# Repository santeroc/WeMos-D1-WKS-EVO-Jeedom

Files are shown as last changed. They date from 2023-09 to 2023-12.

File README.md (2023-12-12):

# WeMos-D1-WKS-EVO-Jeedom
Module permettant de collecter les informations d'un onduleur WKS-EVO pour les récupérer dans une plateforme domotique Jeedom.

## Description détaillée

Ce projet a pour objectif de mettre en œuvre un module permettant de collecter les informations en provenance d’un onduleur solaire hybride WKS, de contrôler à l’aide de deux sondes thermiques la température haute (côté onduleur), la température basse (côté batteries) et de démarrer un système de ventilation si nécessaire. Ce module maintient également la date et l’heure à jour en face du changement d'heure d'été et d'hiver dans l'onduleur (qui n'est pas connecté au réseau informatique). La carte ARCELI WeMos D1 R2, à la base de ce module, embarque une architecture ESP8266 et une carte WIFI intégrée.

## Recommandation
Il est vivement recommandé d'avoir de bonnes connaissances en électricité générale avant de réaliser ou de manipuler tout câblage électrique.
Ceci afin d'appréhender au minimum les risques d'électrocution.

## Structure du projet
- **Documentation\\** : Documentation du projet à lire avant de commencer
	- ``WeMos-D1-WKS-EVO-Jeedom.pdf`` : Document de base nécessaire pour fabriquer le projet et utiliser le code source ci-dessous.
	- ``Plan_De_Cablage_Electrique.pdf`` : Plan de câblage électrique de la solution.
	- ``Plan_De_Cablage_Electrique_Element_Positon_Plan.pdf`` / ``Plan_De_Cablage_Electrique_Element_Positon_Plan.html`` : Composants du plan de câblage avec position sur plan.
	- ``Manuel-WKS-EVO-FR-2021-2-2 - Avec Mes Paramétres.pdf`` : Manuel du WKS-EVO avec mes paramètres et mes commentaires en couleurs.
- **Facade-3D\\**     : Façade imprimable en 3D réalisée avec FreeCAD 0.20
	- ``Facade-v3.FCStd`` : Projet de façade réalisé avec FreeCAD.
	-  ``Facade-v3-Body (Meshed).stl`` : Fichier Mesh de la façade 3D à transmettre pour l'impression 3D.
- **Source\\**        : Code source du projet 
	-  ``WKS_ip_Claude_LCD2004_Et_Temp_H_B_R_T_Reboot_STOndul.ino`` : Code source Arduino à adapter selon la documentaiton ci-dessus.
	
## Version
**Dernière version stable :** 7.8

## Auteur
* **Claude Santero** _alias_ [@santeroc](https://github.com/santeroc)

## Licence

Ce projet est sous licence ``GPLv3`` - voir le fichier [LICENSE.md](LICENSE.md) pour plus d'informations.

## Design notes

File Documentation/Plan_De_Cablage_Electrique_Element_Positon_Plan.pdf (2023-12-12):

KIT SOLAIRE‐DISCOUNT
Arcle | Site | Quanté | Posion / Plan | URL
Seconneur Baerie Unipolaire | Kit Solaire Discount | 1 | B | hps://kitsolaire‐discount.com/fr/coffrets‐de‐protecon/959‐seconneur‐mono‐baerie‐8425511453855.html
PORTE‐FUSIBLE MEGA‐FUSE ‐ VICTRON ENERGY | Kit Solaire Discount | 1 | A | hps://kitsolaire‐discount.com/fr/protecons‐baerie/590‐porte‐fusible‐mega‐fuse‐victron‐energy‐8414824007282.html
FUSIBLE MEGA‐FUSE 200A/32V POUR SYSTEME 12V / 24V | Kit Solaire Discount | 1 | A | hps://kitsolaire‐discount.com/fr/protecons‐baerie/983‐fusible‐mega‐fuse‐200a32v‐pour‐systeme‐12v‐24v‐8414824007282.html
Baerie 100ah 12v Gel décharge Ulmatron | Kit Solaire Discount | 2 | H | hps://kitsolaire‐discount.com/fr/baeries‐solaires‐12v/498‐baerie‐100ah‐12v‐gel‐decharge‐lente‐ulmatron‐8425511454166.html
Cable de Connexion Inter‐baeries 20cm‐25mm² | Kit Solaire Discount | 1 | G | hps://kitsolaire‐discount.com/fr/cable‐connecques‐ouls/88‐cable‐de‐connexon‐inter‐baeries‐20cm‐25mm2‐8414824002911.html
Coffret DC 3kW 25A ‐ 600V ‐ 2 string ‐ 1 MPPT ‐ GENERAL ELECTRIC | Kit Solaire Discount | 1 | J | hps://kitsolaire‐discount.com/fr/coffrets‐de‐protecon/1618‐coffret‐de‐protecon‐dc‐2‐mppt‐2‐parafoudre‐8414824003123.html
PANNEAU SOLAIRE 400W ‐ SHINGLED ‐ CADRE NOIR ‐ ECODELTA | Kit Solaire Discount | 2 | K | hps://kitsolaire‐discount.com/fr/panneaux‐solaires‐rigides/24‐panneau‐solaire‐400w‐shingled‐cadre‐noir‐ecodelta‐8424511843147.html

AMAZON
Arcle | Site | Quanté | Posion / Plan | URL
enjoysolar 15m Câble de raccordement professionnel 4mm² pour panneau solaire avec câble solaire MC‐4 | AMAZON | 1 | N + O | hps://www.amazon.fr/gp/product/B07TLWT9B7/ref=ppx_yo_dt_b_asin_tle_o00_s00?ie=UTF8&th=1
eXODA Câble de Baerie 50cm câble d'alimentaon en cuivre 25 mm² avec cosses à œillets M8 12V câble de Voiture | AMAZON | 1 | C | hps://www.amazon.fr/eXODA‐Baerie‐Dalimentaon‐%C5%93illets‐Voiture/dp/B01C62XC5Y/ref=sr_1_20?keywords=cable+25mm2+m8&qid=1647788559&refinements=p_76%3A437878031&rnid=437877031&rps=1&sprefix=cable+25mm2+M8%2Caps%2C61&sr=8‐20
eXODA Câble de Baerie 150cm câble d'alimentaon en cuivre 25 mm² avec cosses à œillets M8 12V câble de Voiture | AMAZON | 1 | E | hps://www.amazon.fr/eXODA‐Baerie‐Dalimentaon‐%C5%93illets‐Voiture/dp/B01JH1D162/ref=sr_1_2?__mk_fr_FR=%C3%85M%C3%85%C5%BD%C3%95%C3%91&crid=1D0QEDQ3W1SMA&keywords=C%C3%A2ble+de+Baerie+150cm+c%C3%A2ble+d%27alimentaon+en+cuivre+25+mm%C2%B2+avec+cosses+%C3%A0+%C5%93illets+M8&qid=1647789099&sprefix=c%C3%A2ble+de+baerie+150cm+c%C3%A2ble+d%27alimentaon+en+cuivre+25+mm+avec+cosses+%C3%A0+%C5%93illets+m8%2Caps%2C50&sr=8‐2
Clef Triange Pour Ouvrir L'Armoire 32U d'occasion | AMAZON | 1 | | hps://www.amazon.fr/gp/product/B08L3DDSLL/ref=ppx_yo_dt_b_asin_tle_o00_s00?ie=UTF8&psc=1

MYSHOP SOLAIRE
Arcle | Site | Quanté | Posion / Plan | URL
Câble électrique souple de 1.5m en 25mm² ‐ cosse M8 ‐ M10 | MyShop Solaire | 1 | F | hps://www.myshop‐solaire.com/cable‐electrique‐souple‐de‐1‐5m‐ser‐de‐cosse‐m8‐m10‐en‐25mm2‐_r_709_tpid_20_i_3028.html
Câble électrique souple de 0,4m en 25mm² ‐ cosse M8 ‐ M10 | MyShop Solaire | 1 | D | hps://www.myshop‐solaire.com/cable‐bmv‐0‐4m‐ser‐de‐cosse‐m8‐m10‐en‐25mm2‐_r_709_tpid_20_i_946.html
Unifix 800 EGF support de fixaon au sol à viser ou lester | MyShop Solaire | 1 | R | hps://www.myshop‐solaire.com/unifix‐800‐egf‐support‐de‐fixaon‐au‐sol‐a‐viser‐ou‐lester‐_r_1055_i_3002.html
Support dalle béton pour Unifix 800 EGF support de fixaon au sol | MyShop Solaire | 1 | R | hps://www.myshop‐solaire.com/support‐dalle‐beton‐pour‐unifix‐800‐egf‐support‐de‐fixaon‐au‐sol‐_r_1055_i_3003.html#caracterisque

WATTUNEED
Arcle | Site | Quanté | Posion / Plan | URL
Onduleur hybride WKS Evo 3kVA 24V ‐ Code Promo "inthekitchen" | Wa U Need | 1 | I | hps://www.wauneed.com/fr/conversseurs‐230v/12232‐onduleur‐hybride‐wks‐evo‐3kva‐24v‐0712971139954.html
Câble solaire 2X4mm² avec type MC4 (vendu au mètre) / 3m | Wa U Need | 1 | L + M | hps://www.wauneed.com/fr/cables‐et‐connecques/2317‐cable‐solaire‐2x4mm‐avec‐type‐mc4‐0712971133280.html#/longueur_du_c%C3%A2ble‐3m

MAGASINS DIVERS
Arcle | Site | Quanté | Posion / Plan | URL
Castorama (Gouloe, Gaine ICTA,…) | Castorama | 1
Dalle grenaillée Lagos ton pierre 40 x 40 cm, ép.4 cm (Pete Terrasse + Leste) | Castorama | 21 | R | hps://www.castorama.fr/dalle‐grenaillee‐lagos‐ton‐pierre‐40‐x‐40‐cm‐ep‐4‐cm/3454976249258_CAFR.prd
Cables & Vis | Castorama | 1
Plaque de plâtre feu Planodis 250 x 120 cm, ép.12,5 mm | Castorama | 1 | | hps://www.castorama.fr/plaque‐de‐platre‐feu‐planodis‐250‐x‐120‐cm‐ep‐12‐5‐mm‐vendue‐a‐la‐plaque‐zone‐nord/3334160434762_CAFR.prd
Coffret Electrique | Castorama | 1
Armoire Réseau 32U d'occasion | Le Bon Coin | 1

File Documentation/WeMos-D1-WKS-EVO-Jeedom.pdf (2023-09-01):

Dernière Révision : 24/08/2023 - | Réalisation : Claude Santero.

Présentation Du Projet WeMos UI (UPS Interface) :

Le projet WeMos UI a pour objectif de mettre en œuvre une interface permettant de collecter les informations en provenance d’un onduleur solaire hybride WKS, de contrôler à l’aide de deux sondes thermiques la température haute (côté onduleur), la température basse (côté batteries) et de démarrer un système de ventilation si nécessaire. Il maintient également la date et l’heure à jour. La carte ARCELI WeMos D1 R2 embarque une architecture ESP8266 et une carte WIFI intégrée.

Le logiciel embarqué se connecte comme un client au réseau WIFI dont le SSID et le mot de passe sont codés en dur à la compilation. Le système met automatiquement à jour son horloge interne à l’aide d’un client NTP, en prenant en charge l’heure local et les changements d’heure. La date et l’heure sont transmises à l’onduleur au démarrage du module puis tous les jours à 6H du matin via son port série. Un affichage LCD indique la date et l’heure ainsi que la température et le taux d’humidité en partie haute (côté onduleur) et en partie basse (côté batteries). Le logiciel déclenche un relais en fonction de ces températures et / ou en fonction de l’heure pour refroidir l’ensemble. En cas d’anomalie des sondes thermiques ou si la carte venait à être physiquement éteinte, la ventilation se déclenche immédiatement. Le fonctionnement du relais et de la ventilation a été réalisé de tel sorte que ce soit le logiciel qui coupe le relais et donc la ventilation. En l’absence d’un ordre explicit du logiciel sur la carte pour couper le relais, la ventilation est donc toujours en service. Enfin, le logiciel embarque un serveur web permettant présenter les informations collectées sur le port série de l’onduleur, la température et l’humidité au niveau des sondes de température haute et basse et l’état du relais pour la ventilation. Ces informations sont ensuite collectées sur une plateforme Jeedom à l’aide du plugin « Script » toutes les minutes.

Ce document et ce projet sont libres de droit sous licence GPLv3. Merci simplement de respecter son auteur.

### Vous pouvez retrouver l’ensemble de ce projet sur GitHub à l’adresse : https://github.com/santeroc/WeMos-D1-WKS-EVO-Jeedom.git ainsi que toutes mes documentations et tous mes projets sur mon référentiel

GitHub à l’adresse : https://santeroc.github.io.

Liste des articles utilisés dans cette documentation :

- La carte ARCELI :
ARCELI Programme Arduino UNO Compatible avec la Carte de développement WeMos D1 R2 WiFi ESP8266 de Arduino IDE https://www.amazon.fr/gp/product/B07J2QKNHB/ref=ppx_yo_dt_b_asin_title_o02_s00?ie=UTF8&psc=1 (https://www.amazon.fr/gp/product/B07J2QKNHB/ref=ppx_yo_dt_b_asin_title_o02_s00?ie=UTF8&psc=1)
- Câbles de liaisons entre les différents modules :
WheateFull 120 pièces Multicolore Dupont Wire 40pin mâle à femelle + 40pin mâle à mâle + 40pin femelle à femelle Panneau de câbles de cavalier Kit de câbles de ruban pour Arduino https://www.amazon.fr/gp/product/B06XD8NBTZ/ref=ppx_yo_dt_b_asin_title_o06_s00?ie=UTF8&psc=1 (https://www.amazon.fr/gp/product/B06XD8NBTZ/ref=ppx_yo_dt_b_asin_title_o06_s00?ie=UTF8&psc=1)
- Le LCD (étape 1) :
SunFounder IIC I2C TWI Serial 2004 20x4 LCD Module Shield Compatible with Arduino R3 MEGA 2560
https://www.amazon.fr/gp/product/B01GPUMP9C/ref=ppx_yo_dt_b_asin_title_o03_s00?ie=UTF8&psc=1 (https://www.amazon.fr/gp/product/B01GPUMP9C/ref=ppx_yo_dt_b_asin_title_o03_s00?ie=UTF8&psc=1)
- Les sondes thermiques DHT22 AM2302 (étape 2) :
AZDelivery DHT22 AM2302 Capteur de Température et d’Humidité avec Câble Compatible avec Arduino et Raspberry Pi incluant Un E-Book! https://www.amazon.fr/dp/B078SVZB1X/?coliid=I3SM4RYJJS3798&colid=3CZB4MB46B54F&psc=1&ref_=lv_ov_lig_dp_it (https://www.amazon.fr/dp/B078SVZB1X/?coliid=I3SM4RYJJS3798&colid=3CZB4MB46B54F)
- Le convertisseur RS232 (étape 3) :
DollaTek MAX3232 RS232 Serial Port vers TTL Convertisseur Module DB9 Connecteur W / 4 Jump Cables https://www.amazon.fr/gp/product/B07DK3874B/ref=ppx_yo_dt_b_asin_title_o07_s02?ie=UTF8&psc=1 (https://www.amazon.fr/gp/product/B07DK3874B/ref=ppx_yo_dt_b_asin_title_o07_s02?ie=UTF8&psc=1)
- Connecteur de raccordement (étape 4) :
YIOVVOM Connecteur de dérivation DB9 vers borne de câblage RS232 D-SUB adaptateurs série mâles Carte de dérivation de Port Module sans Soudure avec boîtier (Adaptateur série mâle + écrou) https://www.amazon.fr/gp/product/B071DS5GTW/ref=ppx_yo_dt_b_asin_title_o07_s01?ie=UTF8&th=1 (https://www.amazon.fr/gp/product/B071DS5GTW/ref=ppx_yo_dt_b_asin_title_o07_s01?ie=UTF8&th=1)
- Le relais (étape 5) :
ARCELI 5pcs 5V Un Blindage de Carte de Module de Relais à 1 Canal pour Arduino (déclencheur de Bas Niveau) https://www.amazon.fr/gp/product/B07RJFJJZM/ref=ppx_yo_dt_b_asin_title_o00_s00?ie=UTF8&psc=1 (https://www.amazon.fr/gp/product/B07RJFJJZM/ref=ppx_yo_dt_b_asin_title_o00_s00?ie=UTF8&psc=1)
- Le convertisseur 220v – 12v DC (étape 5) :
HuaTec Eaglerise Transformateur LED 12V 15W Tension Constant Ultra Fin pour bande de LED Bloc d'Alimentation Driver LED https://www.amazon.fr/dp/B082VD3QM7/?coliid=I1AE1KZV4JGJ14&colid=TFC9A61478GS&psc=1&ref_=lv_ov_lig_dp_it (https://www.amazon.fr/dp/B082VD3QM7/?coliid=I1AE1KZV4JGJ14&colid=TFC9A61478GS)
- Ventilateur (étape 5) :
Noctua NF-F12 iPPC-2000, Ventilateur Haut Rendement, 3 Broches, 2000 tr./min (120 mm, Noir)
https://www.amazon.fr/dp/B00KEST8PQ/?coliid=I2B3BR5PYC3TEZ&colid=TFC9A61478GS&psc=1&ref_=lv_ov_lig_dp_it (https://www.amazon.fr/dp/B00KEST8PQ/?coliid=I2B3BR5PYC3TEZ&colid=TFC9A61478GS)
- Boite et sa façade (étape 9) :
JOYKK Boîte de Projet pour boîtier électronique en Plastique étanche https://www.amazon.fr/gp/product/B07PK4BPM4/ref=ppx_yo_dt_b_asin_title_o03_s00?ie=UTF8&psc=1 (https://www.amazon.fr/gp/product/B07PK4BPM4/ref=ppx_yo_dt_b_asin_title_o03_s00?ie=UTF8&psc=1)

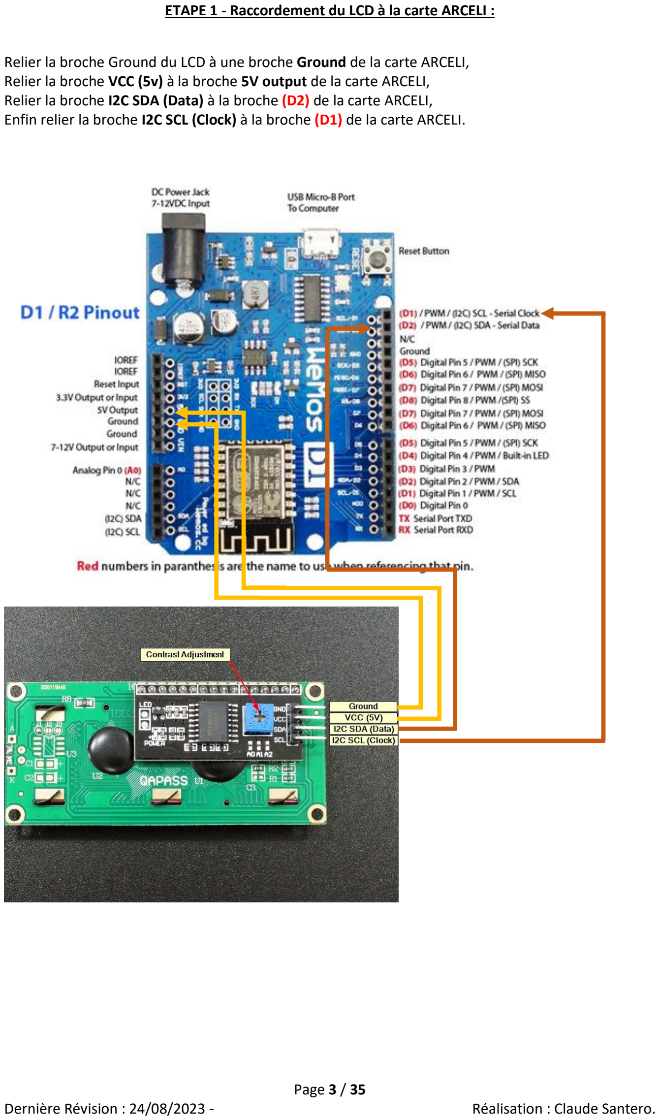
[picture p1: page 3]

ETAPE 1 - Raccordement du LCD à la carte ARCELI :

Relier la broche Ground du LCD à une broche Ground de la carte ARCELI, Relier la broche VCC (5v) à la broche 5V output de la carte ARCELI, Relier la broche I2C SDA (Data) à la broche (D2) de la carte ARCELI, Enfin relier la broche I2C SCL (Clock) à la broche (D1) de la carte ARCELI.

ETAPE 2 - Raccordement des sondes DHT22 AM2302 à la carte ARCELI :

Relier les broches « - » des DHT22 à une broche Ground de la carte ARCELI, Relier les broches « + » des DHT22 à la broche 5V output de la carte ARCELI, Relier la broche OUT du DHT Bas (B) à la broche (D3) de la carte ARCELI, Enfin relier la broche OUT du DHT Haut (H) à la broche (D4) de la carte ARCELI.

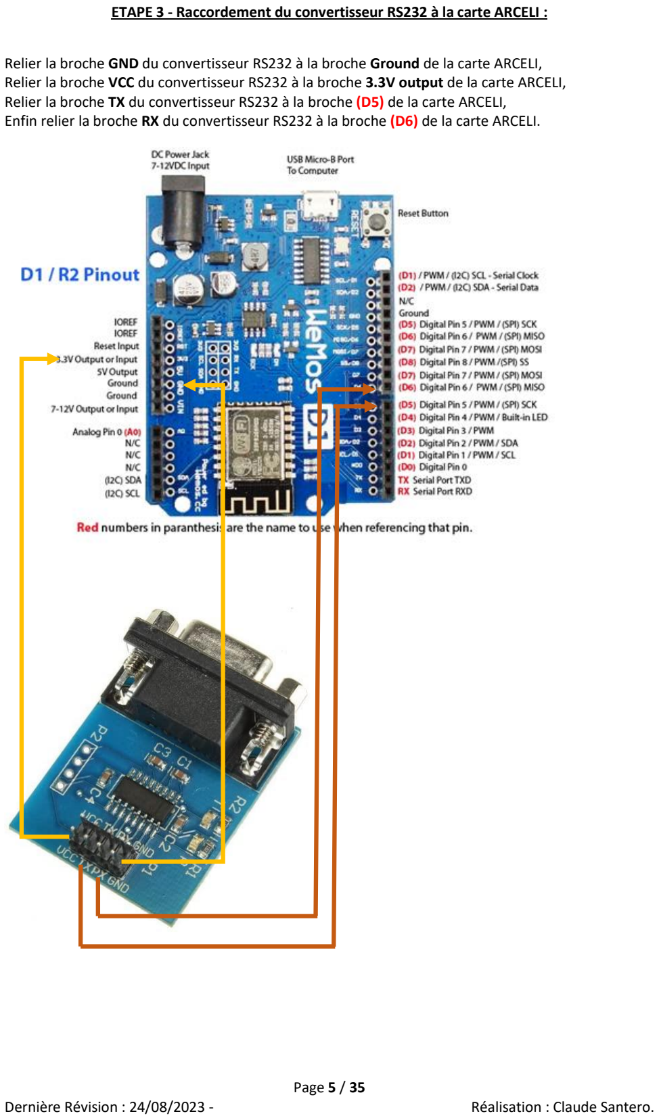
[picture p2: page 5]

ETAPE 3 - Raccordement du convertisseur RS232 à la carte ARCELI :

Relier la broche GND du convertisseur RS232 à la broche Ground de la carte ARCELI, Relier la broche VCC du convertisseur RS232 à la broche 3.3V output de la carte ARCELI, Relier la broche TX du convertisseur RS232 à la broche (D5) de la carte ARCELI,
Enfin relier la broche RX du convertisseur RS232 à la broche (D6) de la carte ARCELI.

ETAPE 4 - Raccordement du convertisseur RS232 à l’onduleur :

Le connecteur RJ45 se connecte au port COM (série ou RS232) de l’onduleur. Le connecteur RS232 (DB9) vient se connecter sur le convertisseur RS232 préparé en étape 3.

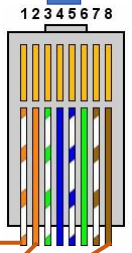
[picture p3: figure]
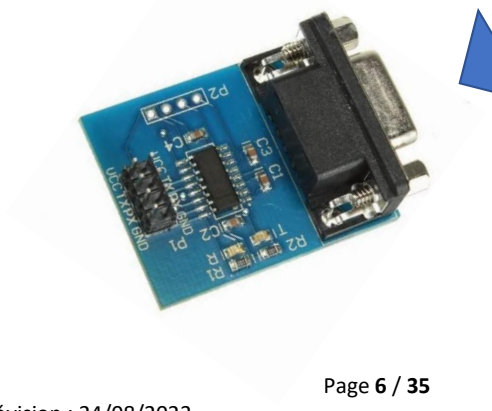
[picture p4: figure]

Vers Convertisseur
RS232 (étape 3).

Vers Onduleur WKS.

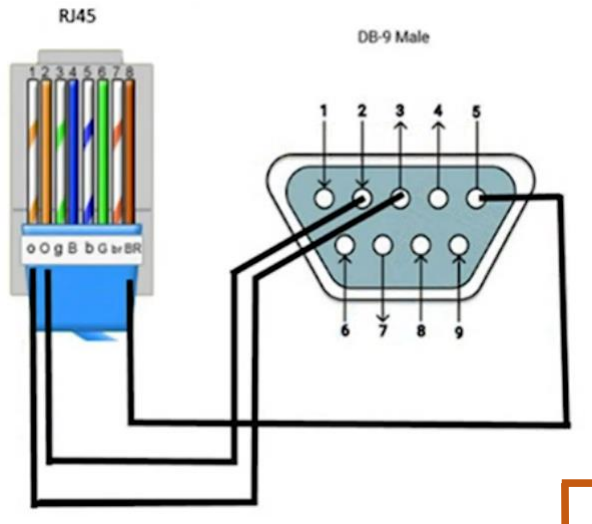
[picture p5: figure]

Vers ventilateurs
en respectant la
polarité (+ fil
rouge du
ventilateur et – fil
noir). Le fil jaune
du ventilateur est
inutile.

ETAPE 5 - Raccordement du relais à la carte ARCELI :

Relier la broche GND du relais à la broche Ground de la carte ARCELI,
Relier la broche VCC du relais à la broche 5V output de la carte ARCELI,
Enfin relier la broche IN du relais à la broche (D7) de la carte ARCELI.

Sur le bornier de sortie du relais, couper la phase de l’alimentation secteur des ventilateurs avec les connecteurs COM (Common) au centre et le connecteur NC (Normaly Closed).

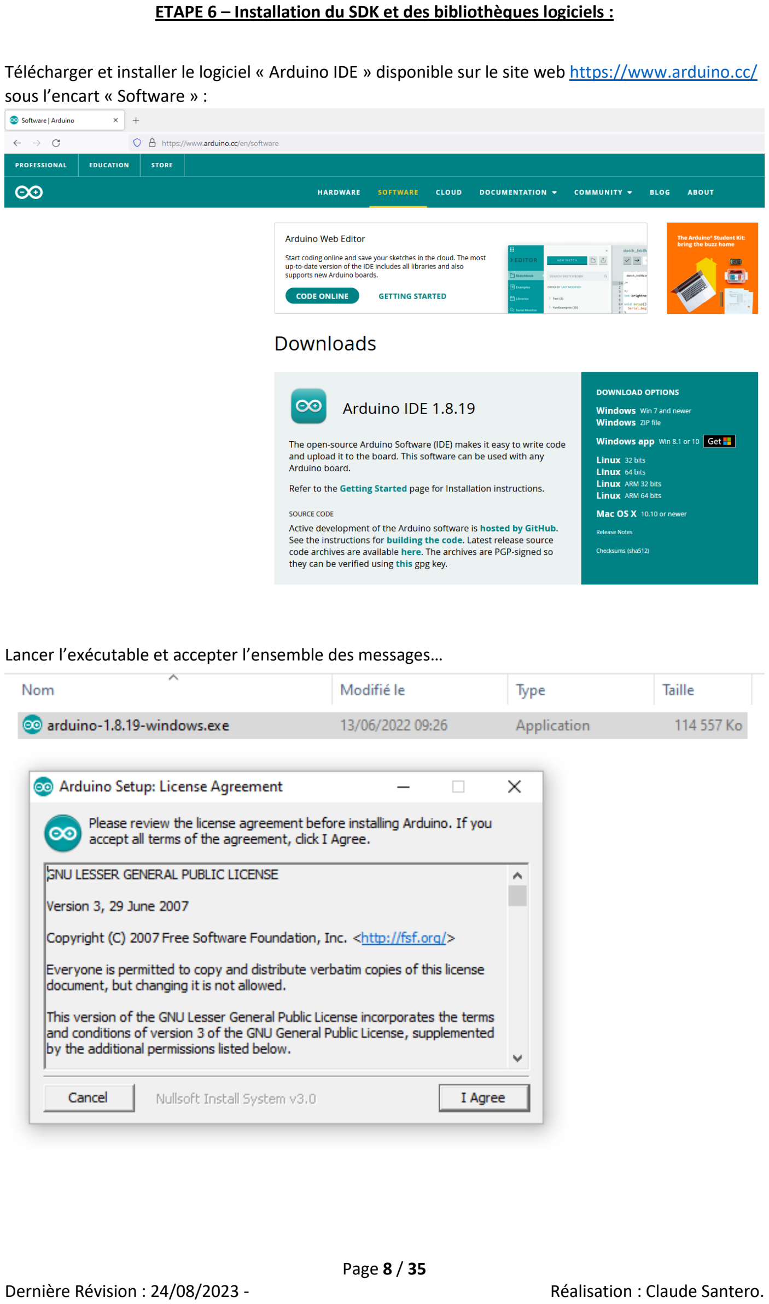
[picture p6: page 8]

ETAPE 6 – Installation du SDK et des bibliothèques logiciels :

Télécharger et installer le logiciel « Arduino IDE » disponible sur le site web https://www.arduino.cc/ sous l’encart « Software » :

Lancer l’exécutable et accepter l’ensemble des messages…

Faire « Next > »…

Faire « Install »…

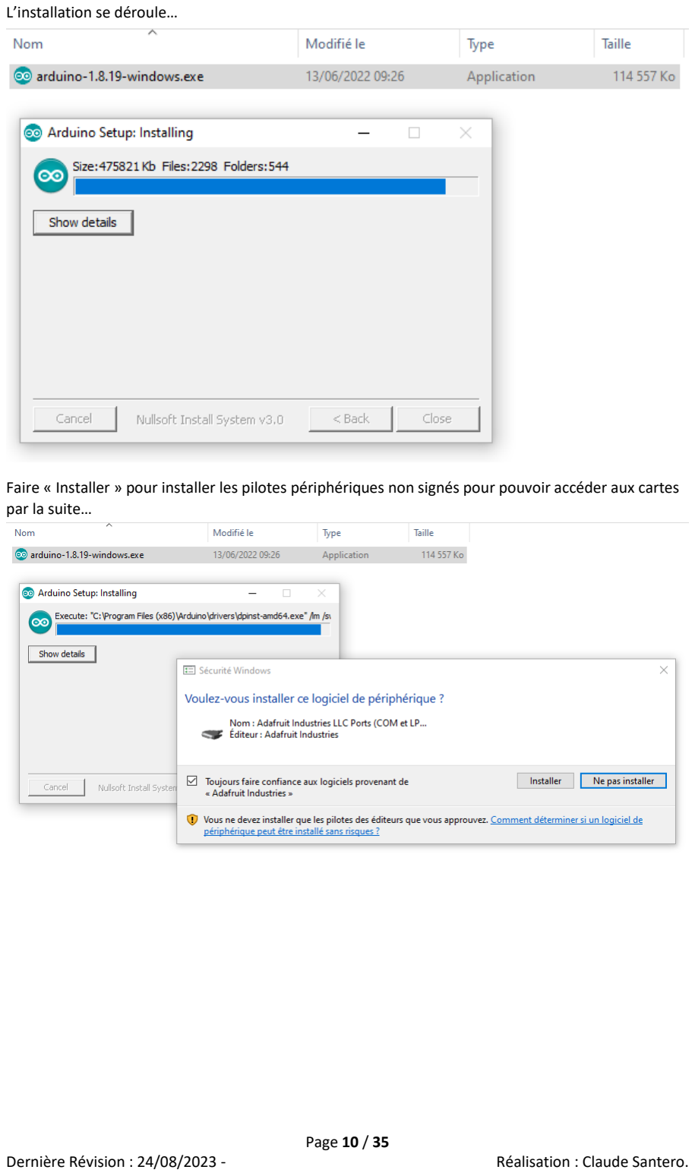
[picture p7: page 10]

L’installation se déroule…

Faire « Installer » pour installer les pilotes périphériques non signés pour pouvoir accéder aux cartes par la suite…

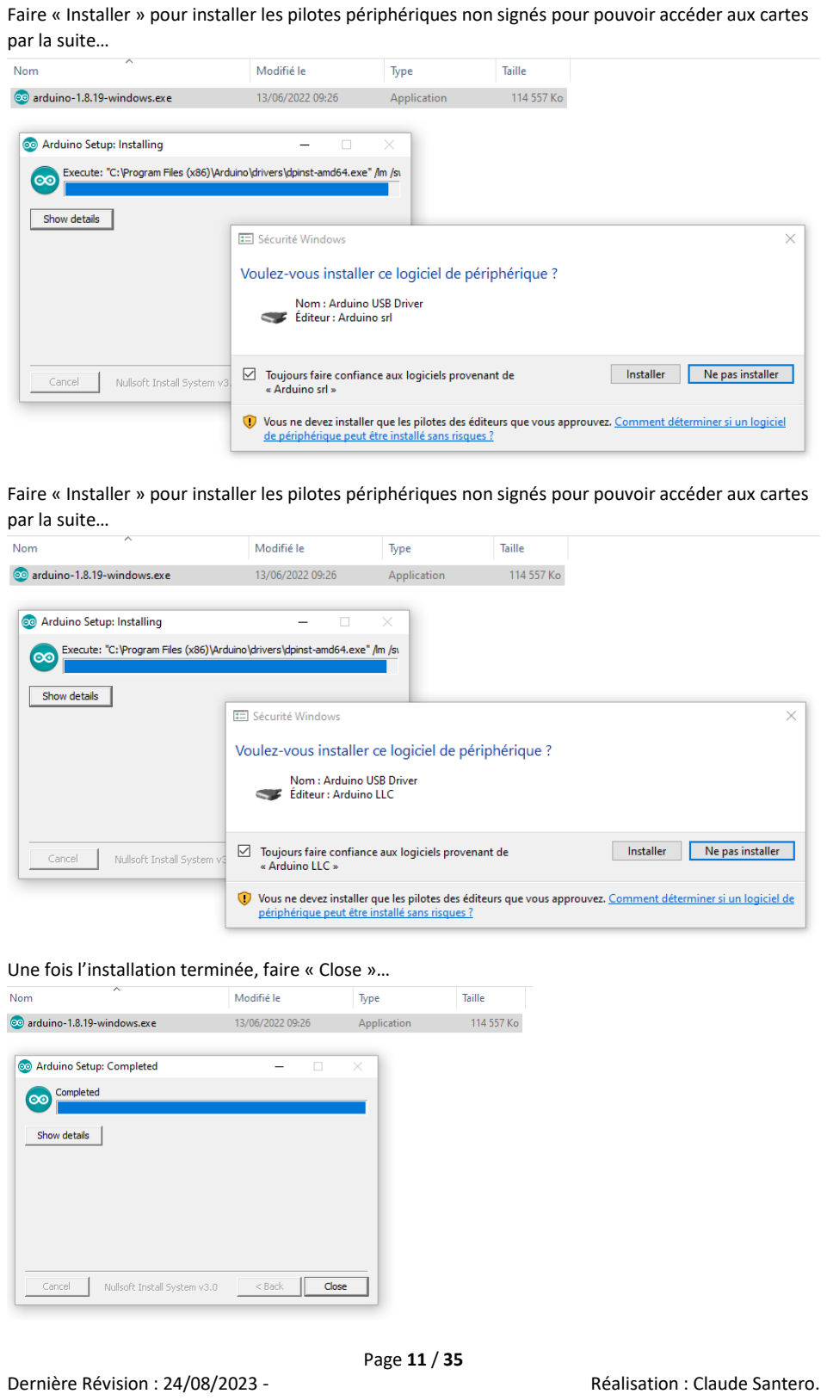
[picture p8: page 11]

Faire « Installer » pour installer les pilotes périphériques non signés pour pouvoir accéder aux cartes par la suite…

Faire « Installer » pour installer les pilotes périphériques non signés pour pouvoir accéder aux cartes par la suite…

Une fois l’installation terminée, faire « Close »…

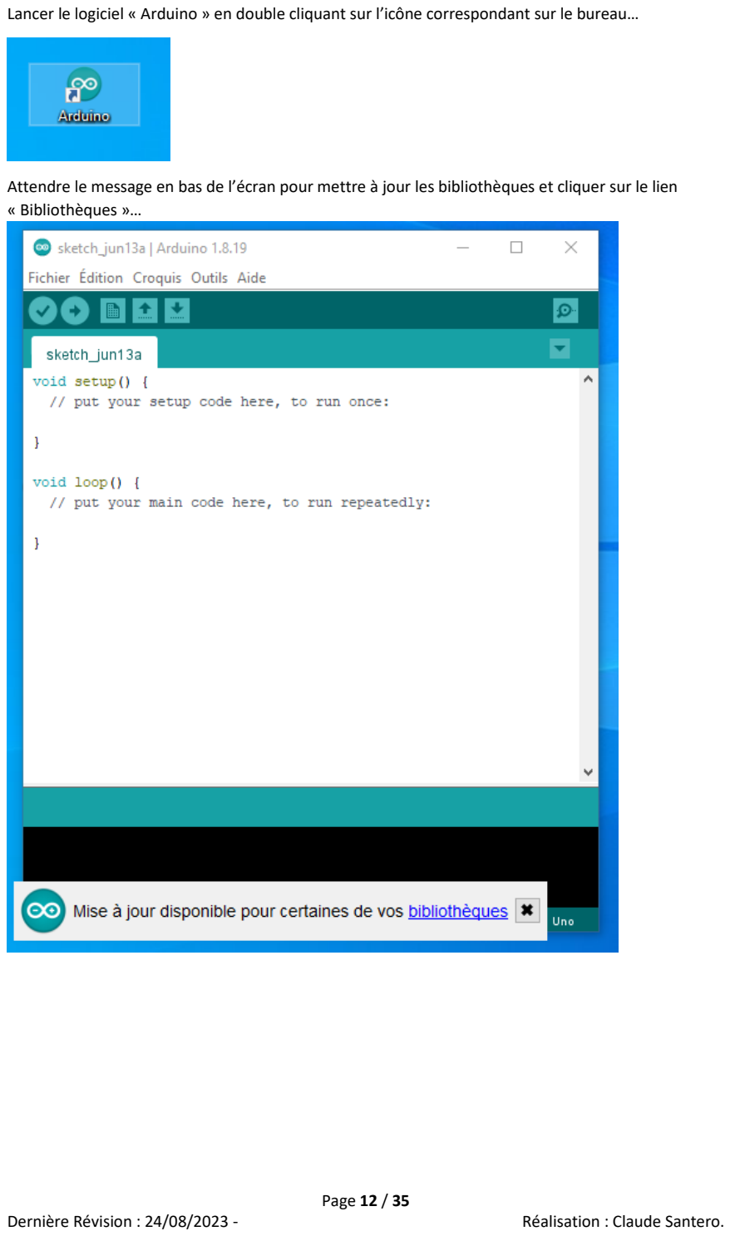
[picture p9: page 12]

Lancer le logiciel « Arduino » en double cliquant sur l’icône correspondant sur le bureau…

Attendre le message en bas de l’écran pour mettre à jour les bibliothèques et cliquer sur le lien « Bibliothèques »…

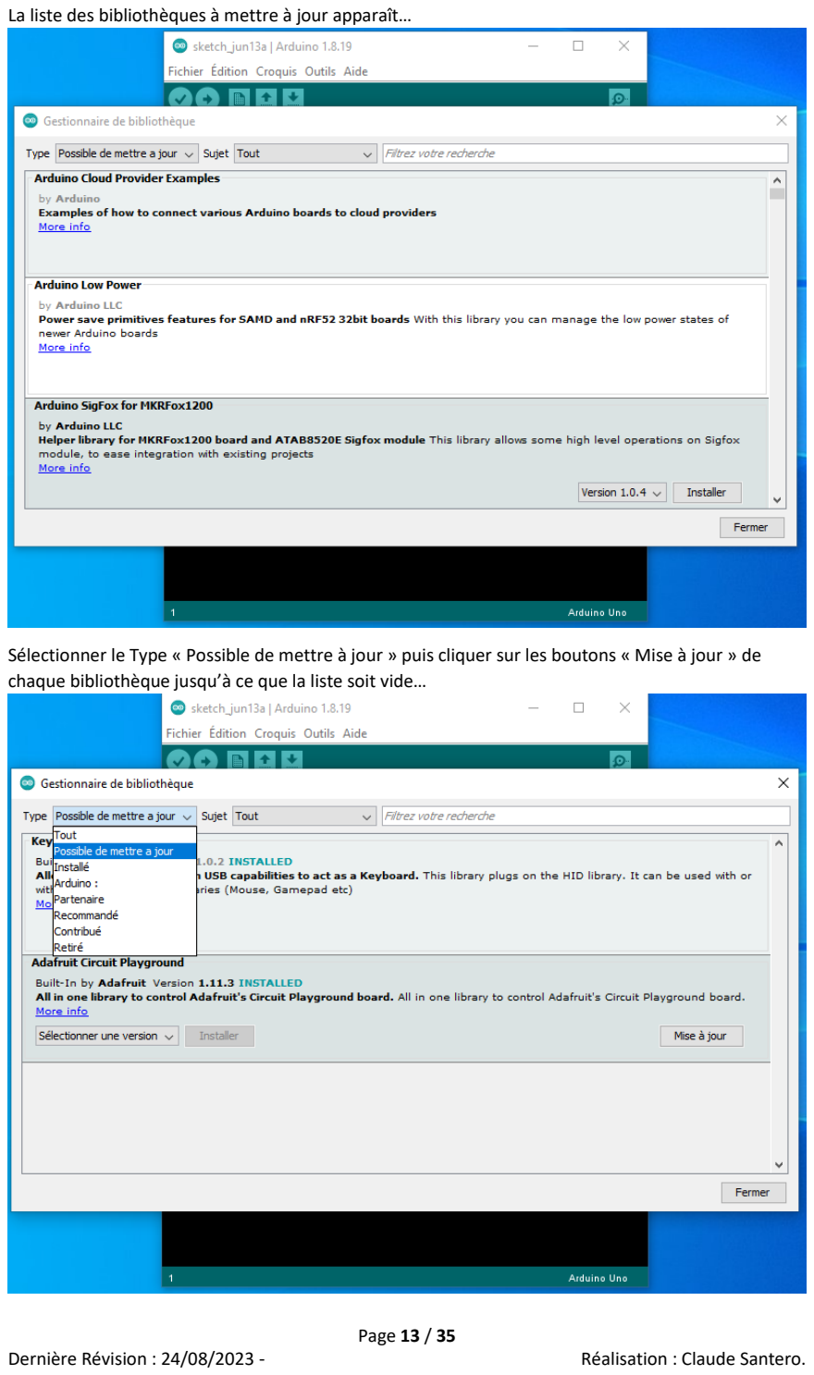
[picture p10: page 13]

La liste des bibliothèques à mettre à jour apparaît…

Sélectionner le Type « Possible de mettre à jour » puis cliquer sur les boutons « Mise à jour » de chaque bibliothèque jusqu’à ce que la liste soit vide…

Lorsque des dépendances sont nécessaires faire « Install all »…

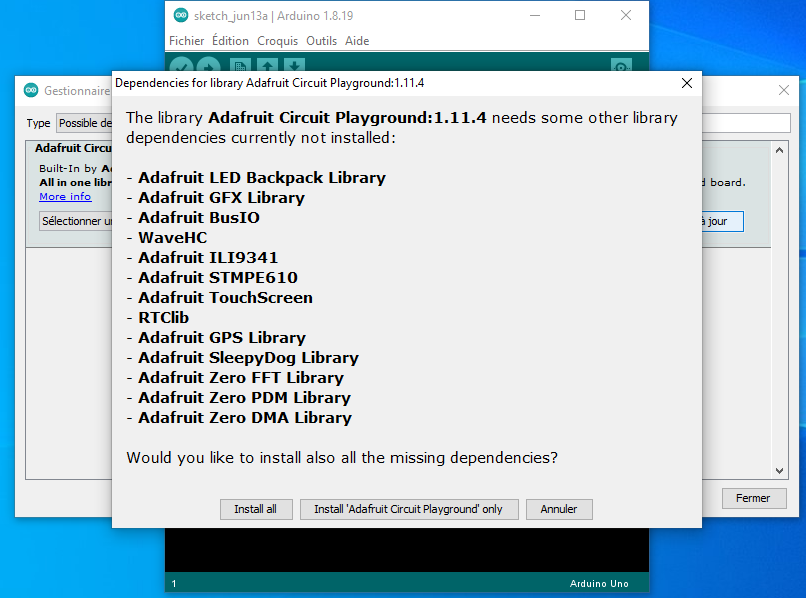
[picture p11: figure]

Lorsque les bibliothèques sont à jour, il faut installer les bibliothèques matérielles qui permettent de prendre en charge la carte ARCELI WEMOS D1 R2.

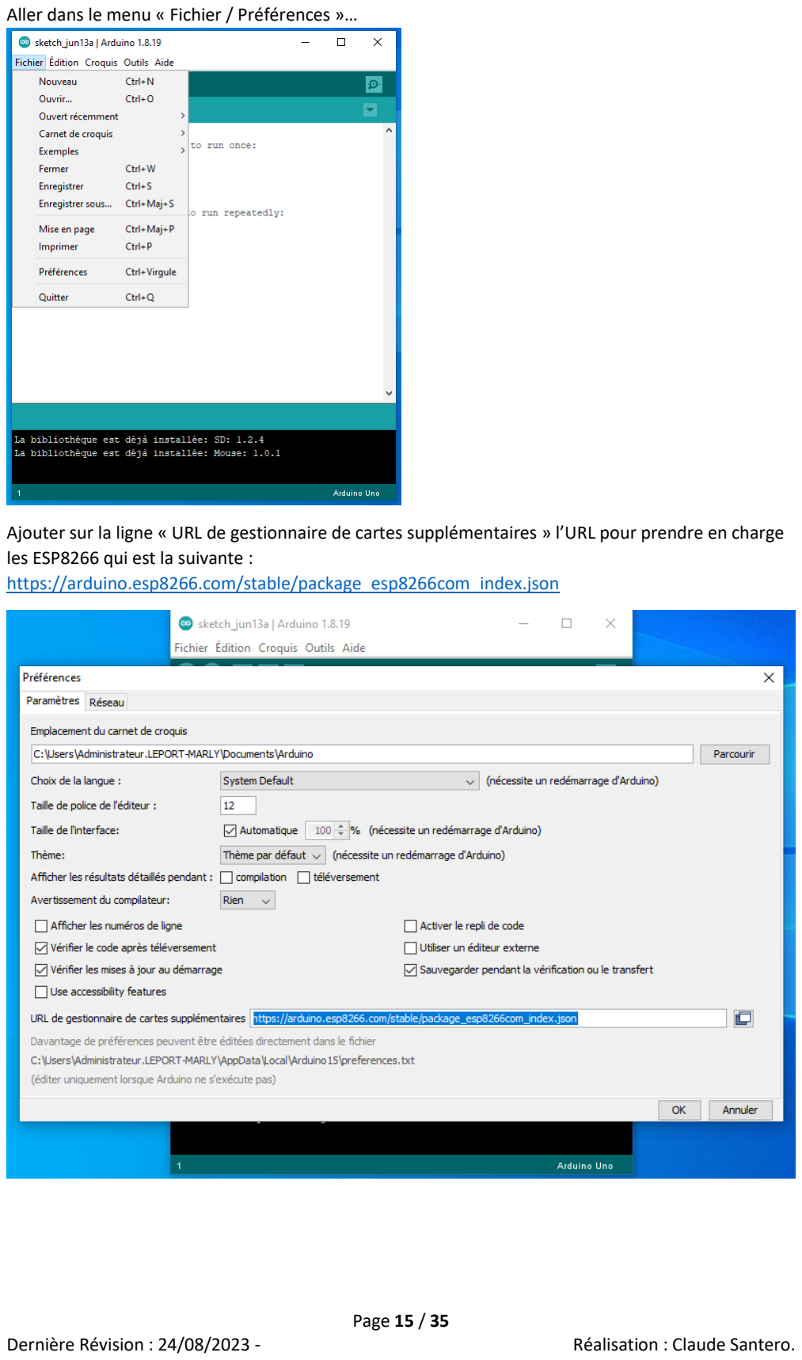
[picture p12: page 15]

Aller dans le menu « Fichier / Préférences »…

Ajouter sur la ligne « URL de gestionnaire de cartes supplémentaires » l’URL pour prendre en charge les ESP8266 qui est la suivante :
https://arduino.esp8266.com/stable/package_esp8266com_index.json

Aller dans le menu « Outils / Type de carte : ‘’Arduino Uno’’ / Gestionnaire de carte »…

Comme pour le gestionnaire de bibliothèques, mettre à jour ce qui peut être mis à jour…

SI besoin installer les pilotes non signés…

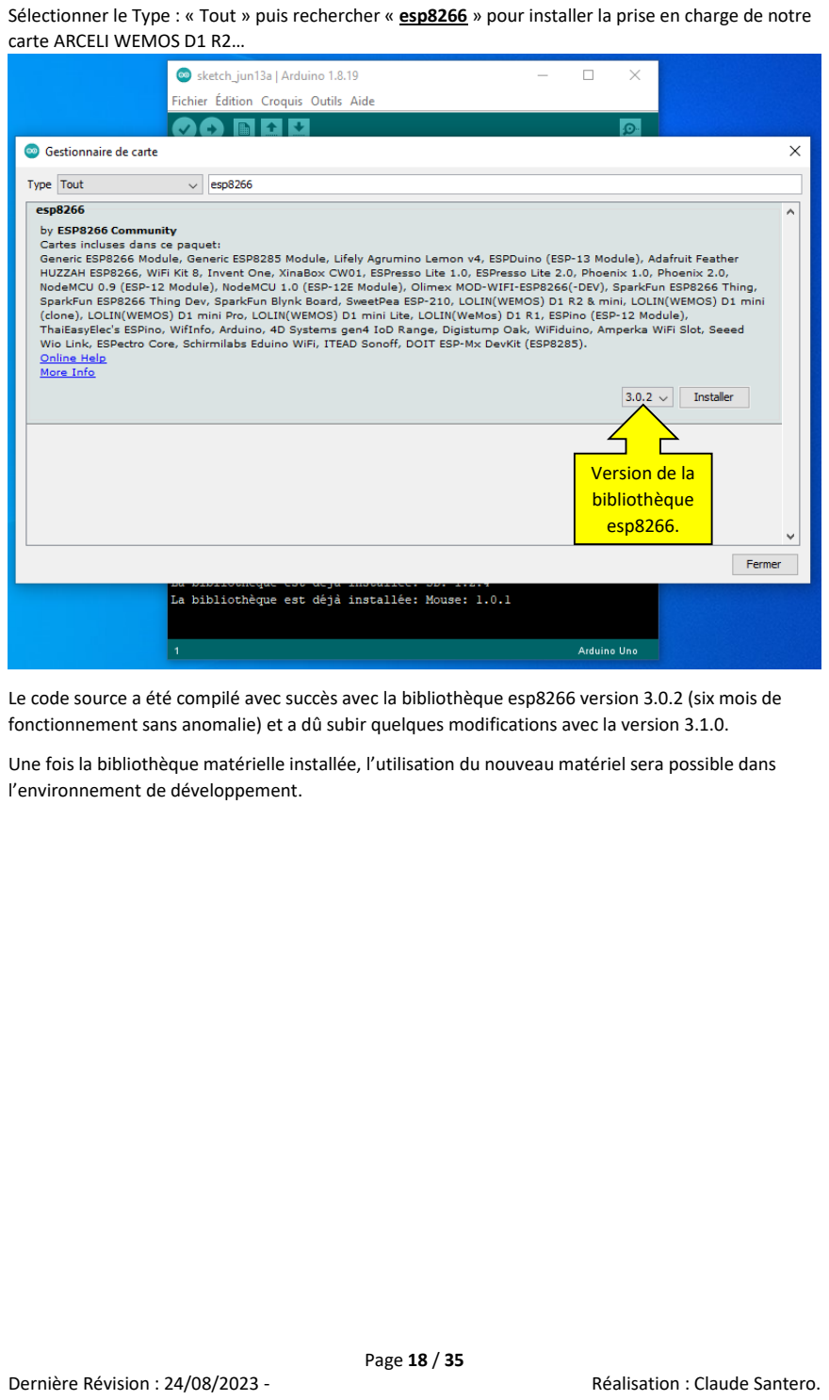
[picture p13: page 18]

Sélectionner le Type : « Tout » puis rechercher « esp8266 » pour installer la prise en charge de notre carte ARCELI WEMOS D1 R2…

Le code source a été compilé avec succès avec la bibliothèque esp8266 version 3.0.2 (six mois de fonctionnement sans anomalie) et a dû subir quelques modifications avec la version 3.1.0.

Une fois la bibliothèque matérielle installée, l’utilisation du nouveau matériel sera possible dans l’environnement de développement.

Version de la
bibliothèque
esp8266.

Sélectionner la carte dans le menu « Outils / type de carte / ESP8266 Boards (3.0.2) / LOLIN(WEMOS) D1 R2 & mini ». Le code a été adapté pour fonctionner avec la version ESP8266 Boards (3.1.0).

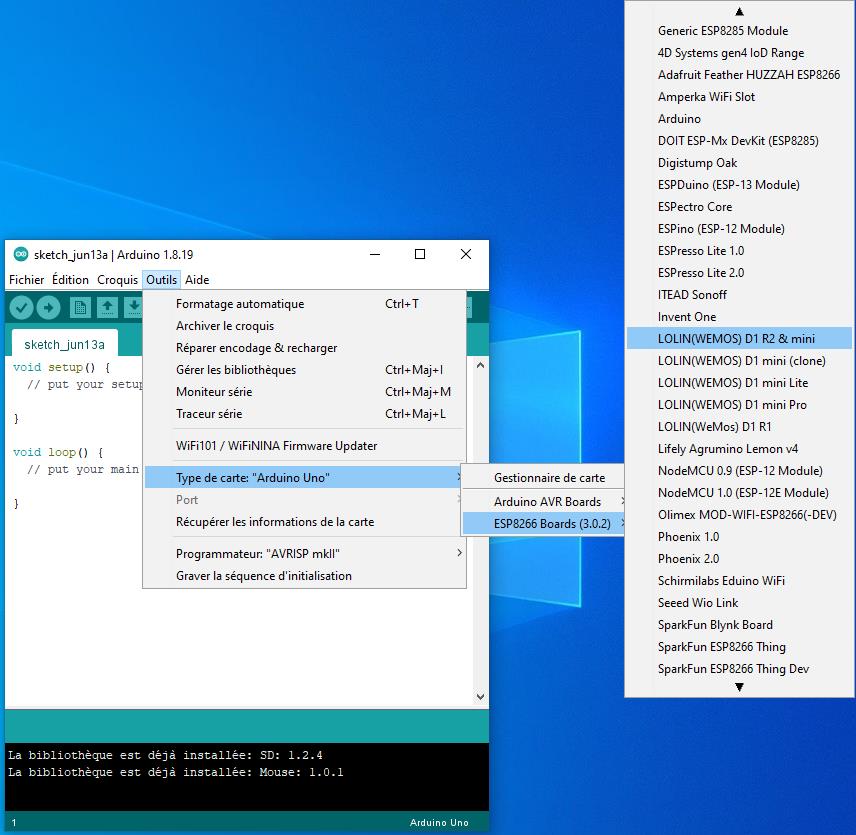
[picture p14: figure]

Maintenant que le matériel est reconnu par le logiciel « Arduino IDE », nous devons ajouter les bibliothèques nécessaires à l’exploitation des différents constituant du projet (WIFI, Relais, sondes DHT22, LCD, etc…).

Aller dans le menu « Outils / Gérer les bibliothèques »…

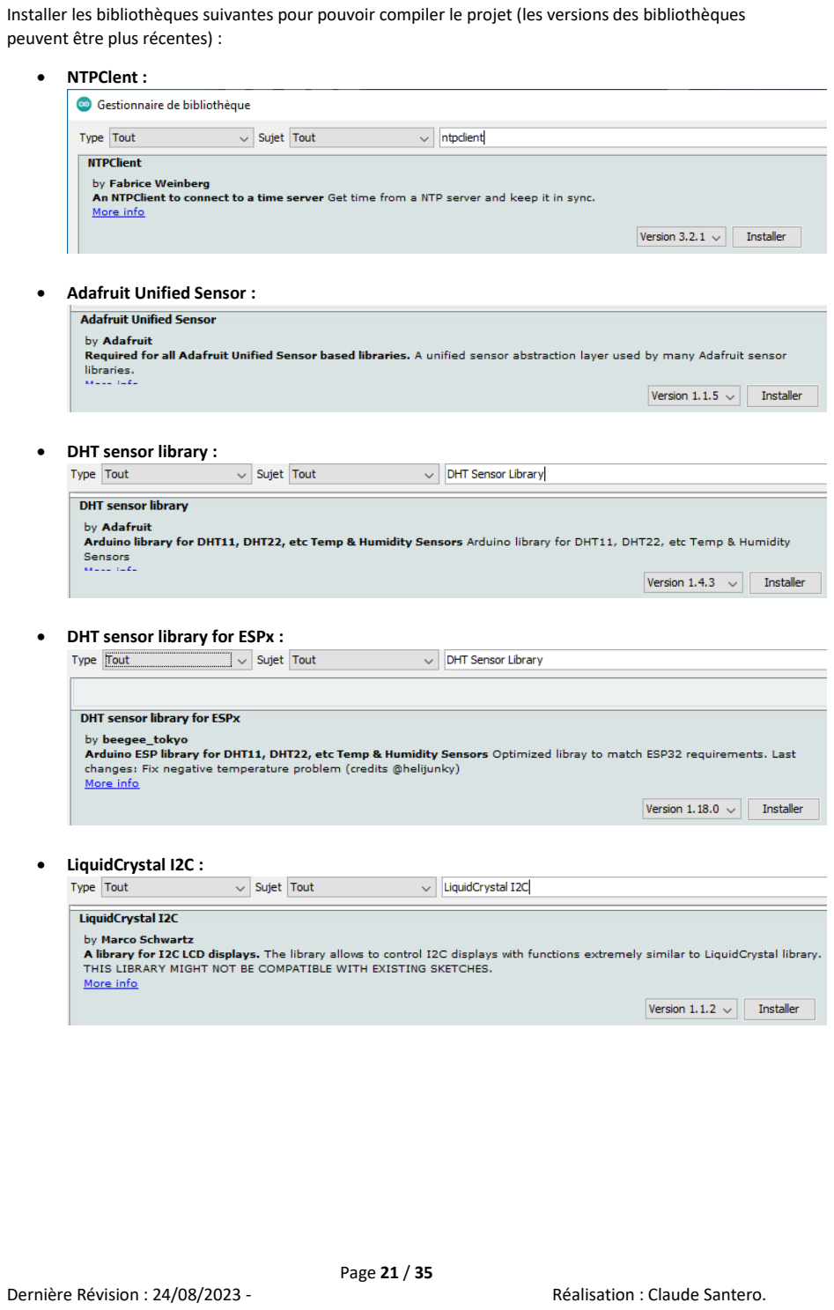
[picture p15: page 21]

Installer les bibliothèques suivantes pour pouvoir compiler le projet (les versions des bibliothèques peuvent être plus récentes) :

- NTPClent :
- Adafruit Unified Sensor :
- DHT sensor library :
- DHT sensor library for ESPx :
- LiquidCrystal I2C :

- Time :

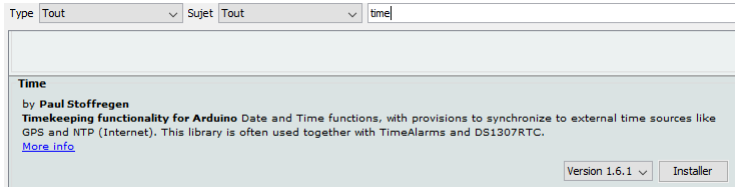
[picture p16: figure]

- Timezone :

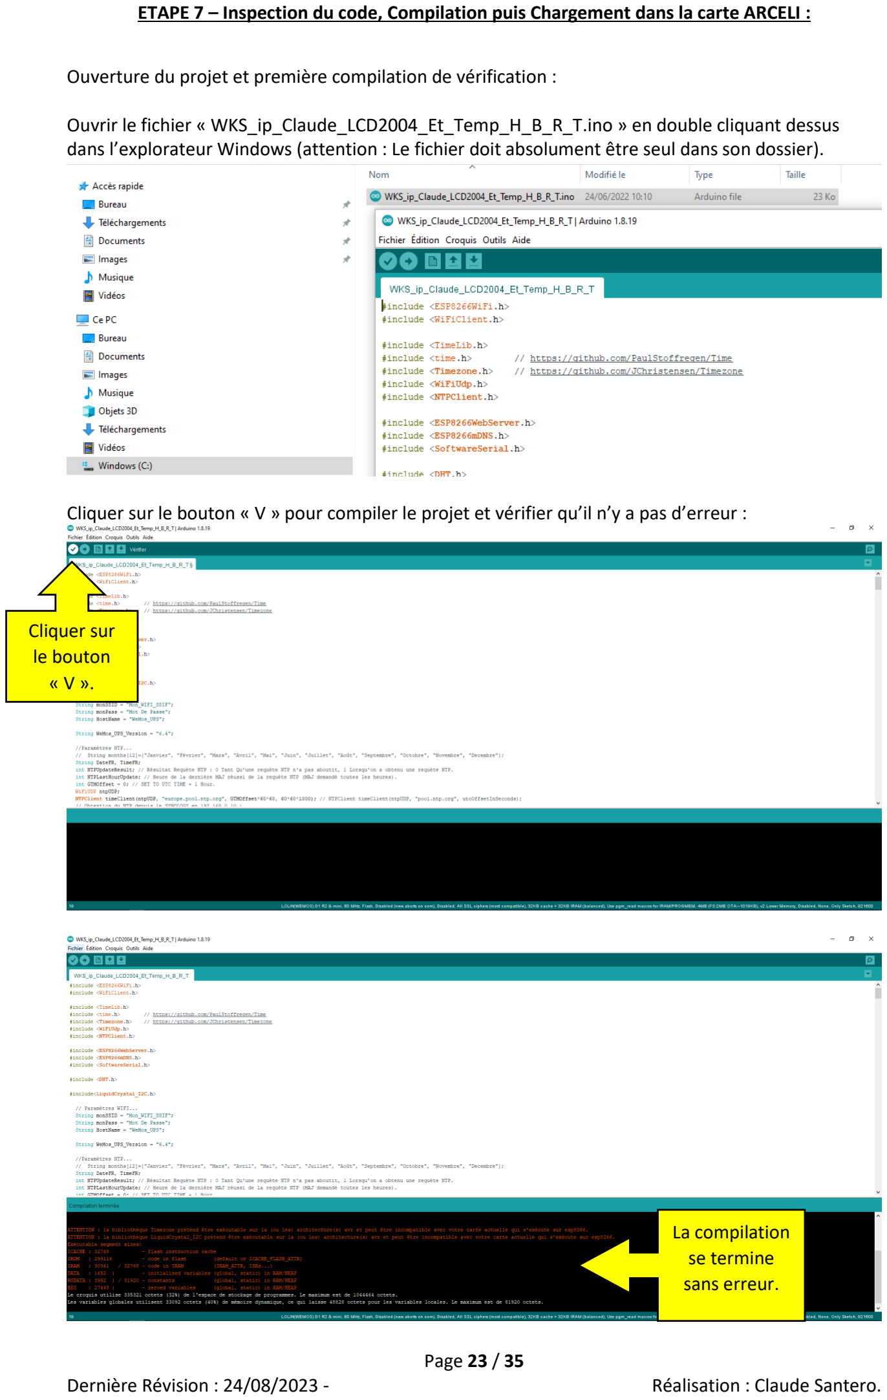
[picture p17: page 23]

ETAPE 7 – Inspection du code, Compilation puis Chargement dans la carte ARCELI :

Ouverture du projet et première compilation de vérification :

Ouvrir le fichier « WKS_ip_Claude_LCD2004_Et_Temp_H_B_R_T.ino » en double cliquant dessus dans l’explorateur Windows (attention : Le fichier doit absolument être seul dans son dossier).

Cliquer sur le bouton « V » pour compiler le projet et vérifier qu’il n’y a pas d’erreur :

Cliquer sur
le bouton
« V ».

La compilation
se termine
sans erreur.

Si la compilation se déroule bien (en version 3.0.2 de la bibliothèque esp8266), seul deux avertissements sans importance apparaissent dans la fenêtre de compilation :

ATTENTION : la bibliothèque Timezone prétend être exécutable sur la (ou les) architecture(s) avr et peut être incompatible avec votre carte actuelle qui s'exécute sur esp8266.
ATTENTION : la bibliothèque LiquidCrystal_I2C prétend être exécutable sur la (ou les) architecture(s) avr et peut être incompatible avec votre carte actuelle qui s'exécute sur esp8266.
Executable segment sizes:
ICACHE : 32768 | - flash instruction cache
IROM | : 299116 | - code in flash | (default or ICACHE_FLASH_ATTR)
IRAM | : 30561 | / 32768 - code in IRAM | (IRAM_ATTR, ISRs...)
DATA | : 1652 | ) | - initialized variables (global, static) in RAM/HEAP
RODATA : 3992 | ) / 81920 - constants | (global, static) in RAM/HEAP
BSS | : 27448 ) | - zeroed variables | (global, static) in RAM/HEAP
Le croquis utilise 335321 octets (32%) de l'espace de stockage de programmes. Le maximum est de 1044464 octets.
Les variables globales utilisent 33092 octets (40%) de mémoire dynamique, ce qui laisse 48828 octets pour les variables locales. Le maximum est de 81920 octets.

En version 3.1.0 de la bibliothèque esp8266 :

ATTENTION : la bibliothèque Timezone-master prétend être exécutable sur la (ou les) architecture(s) avr et peut être incompatible avec votre carte actuelle qui s'exécute sur esp8266.
ATTENTION : la bibliothèque LiquidCrystal_I2C prétend être exécutable sur la (ou les) architecture(s) avr et peut être incompatible avec votre carte actuelle qui s'exécute sur esp8266.
. Variables and constants in RAM (global, static), used 33208 / 80192 bytes (41%)
║ | SEGMENT | BYTES | DESCRIPTION
╠══ DATA | 1648 | initialized variables
╠══ RODATA | 4008 | constants
╚══ BSS | 27552 | zeroed variables
. Instruction RAM (IRAM_ATTR, ICACHE_RAM_ATTR), used 63019 / 65536 bytes (96%)
║ | SEGMENT | BYTES | DESCRIPTION
╠══ ICACHE | 32768 | reserved space for flash instruction cache
╚══ IRAM | 30251 | code in IRAM
. Code in flash (default, ICACHE_FLASH_ATTR), used 299500 / 1048576 bytes (28%)
║ | SEGMENT | BYTES | DESCRIPTION
╚══ IROM | 299500 | code in flash

A ce stade, il est nécessaire de configurer certains paramètres directement dans le code avant de l’envoyer dans la carte ARCELI :

// Paramètres WIFI...
static const String monSSID = "Insérer ICI le SSID de votre WIFI";
static const String monPass = "Insérer ICI le mot de passe de votre WIFI";
static const String HostName = "Insérer ICI le nom d’hôte de votre périphérique";

static const String WeMos_UPS_Version = "6.9"; // Vous pouvez changer le No de version si nécessaire.

// Paramètre Du Relais Ventilos...
static const float TempStartWKS = 32.50; | // Température de déclenchement des ventilos pour
| le WKS.
static const float TempStopWKS = 29.50; | // Température d'arrêt des ventilos pour le WKS si
| ventilos démarrés.
static const float TempStartBat = 25.50; | // Température de déclenchement des ventilos pour
| les batteries.
static const float TempStopBat = 22.50; | // Température d'arrêt des ventilos pour les
| batteries si ventilos démarrés.
static const int HStart = 2; | // Heure de lancement des ventilos forcée.
static const int HStop = 7; | // Heure d'arrêt des ventilos forcée (heure comprise
| donc 7 signifie arrêt à 8H).

Localiser la fonction void setup() pour y modifier les derniers paramètres réseaux suivants :
ATTENTION : Les paramètres suivants sont séparés par des virgules et non des par points.
IPAddress LAN_ADDR(192,168,0,6); | // Adresse IP du périphérique.
IPAddress LAN_GW(192,168,0,1); | // Adresse IP de la passerelle.
IPAddress LAN_SUBNET(255,255,255,0); | // Masque de sous réseau.
IPAddress LAN_DNS(192,168,0,1); | // Adresse IP du serveur DNS.

Avant d’envoyer le code dans la carte ARCELI, il faut trouver le port série sur lequel est connecté la carte ARCELI sur l’ordinateur. Reliez le connecteur micro-USB de la carte ARCELI à un port USB du PC puis ouvrez le gestionnaire de périphériques. Repérez sous la section Ports (COM et LPT) un périphérique qui porterait un nom comme CH340. En face figure le No du port de COM à configurer dans le logiciel « Arduino IDE ». Dans l’exemple ci-dessous il s’agit du port COM4.

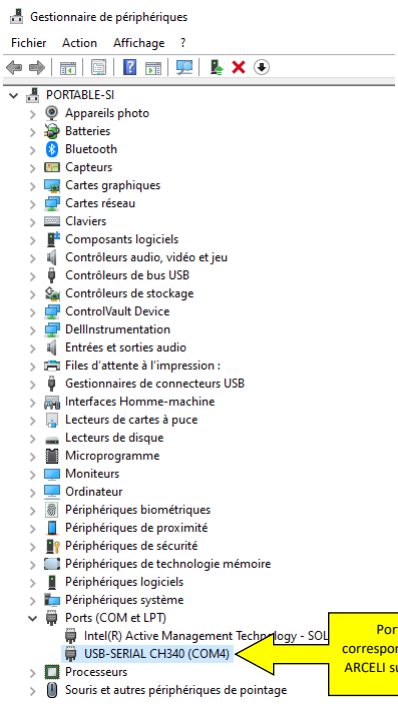
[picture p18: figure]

Port de COM
correspondant à la carte
ARCELI sur l’ordinateur.

Dans le logiciel « Arduino IDE », ouvrir le menu « Outils / Port: » puis sélectionner le port de COM correspondant à celui que vous avez trouvé ci-dessus. Dans notre exemple il s’agit de COM4.

Ouvrir le menu
« Outils / Port: » et
sélectionner le port
adéquat.

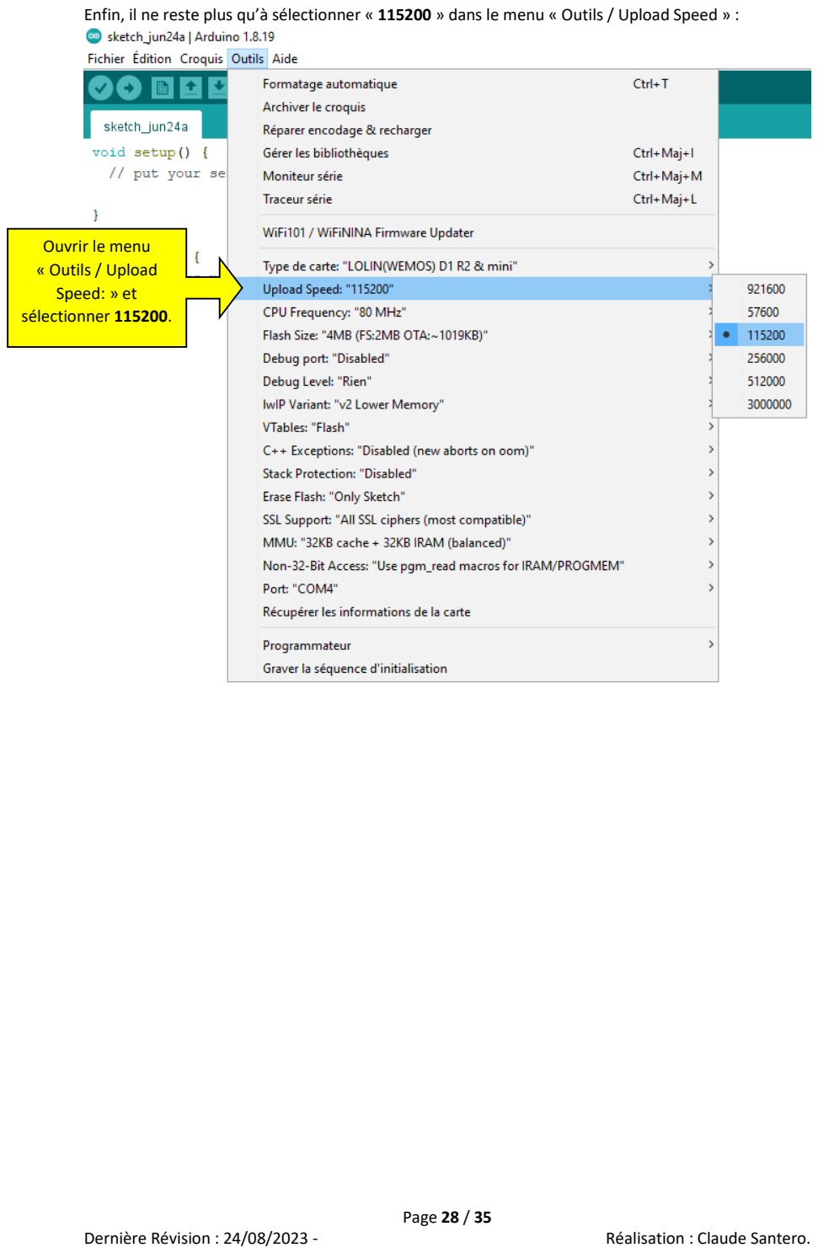
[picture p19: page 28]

Enfin, il ne reste plus qu’à sélectionner « 115200 » dans le menu « Outils / Upload Speed » :

Ouvrir le menu
« Outils / Upload
Speed: » et
sélectionner 115200.

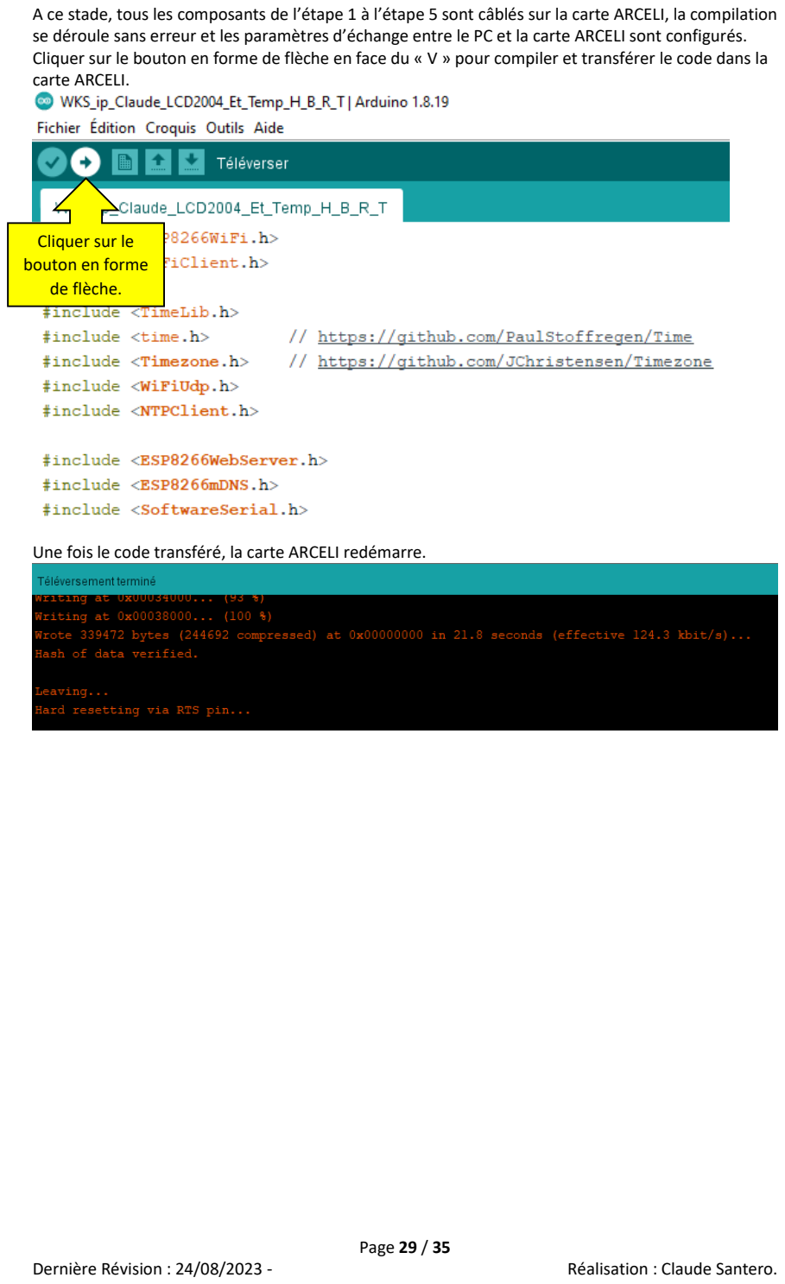
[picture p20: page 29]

A ce stade, tous les composants de l’étape 1 à l’étape 5 sont câblés sur la carte ARCELI, la compilation se déroule sans erreur et les paramètres d’échange entre le PC et la carte ARCELI sont configurés. Cliquer sur le bouton en forme de flèche en face du « V » pour compiler et transférer le code dans la carte ARCELI.

Une fois le code transféré, la carte ARCELI redémarre.

Cliquer sur le
bouton en forme
de flèche.

ETAPE 8 – Interrogation de la carte ARCELI dans JEEDOM :

Lorsque le module ARCELI est connecté au réseau WIFI et qu’il accède à internet, il se met immédiatement à jour et affiche l’heure. La ligne suivante sur le LCD présente un indicateur qui évolue à chaque requête qui sont faites à la carte. Ensuite s’affiche TH et TB pour indiquer la température de la sonde Haute (WKS) et la température Basse (celle des batteries).

Exemple d’affichage :
*21/06/2022 - 16:30*
<- - ->
TH : 30.50°C/41.10%.
TB : 22.10°C/54.20%.

Les caractères mis en rouges dans l’exemple ci-dessus fournissent des informations complémentaires :

En face de la date et de l’heure 3 cas possibles :
Rien | : Ventilos arrêtés normalement.
* | : Température au-dessus de TempStopWKS ou TempStopBat dans le code.
+ | : Régulation, les ventilos fonctionnent dans la plage horaire comprise entre HStart et HStop
| dans le code.

En face de chaque ligne TH et TB le dernier caractère en rouge peut-être :
. | : (Un point) La température est inférieure TempStartWKS pour TH et TempStartBat pour TB
| dans le code.
* | : La température TH est supérieure à TempStartWKS pour TH et TempStartBat pour TB dans
| le code.

<- - -> : Barre d’avance qui progresse à chaque fois qu’on interroge le module en http.

Une fois configuré et mis en service, le projet est accessible via un simple navigateur web en accédant en http à l’adresse IP configurée dans le code ci-dessus du module ARCELI. Dans notre exemple l’adresse IP de notre carte ARCELI est 192.168.0.6, il suffit de saisir dans la barre d’adresse de son navigateur web l’adresse http://192.168.0.6 puis [ENTREE] pour obtenir les informations du module. A chaque requête http traitée par le module ARCELI, le barre graphe sur le LCD progresse (<- - ->). Voici un exemple de page obtenu après l’exécution d’une requête dans un navigateur web :

Voici à quoi ressemble le code source de la page :

<!DOCTYPE HTML>
<html>
<head>
</head>
<body style='text-align:center;'>
<div class='infos_output_frequence'>49.90</div><br /> <div class='infos_output_apparent_power'>368</div><br /> <div class='infos_output_active_power'>339</div><br /> <div class='infos_output_load_percent'>12</div><br /> <div class='infos_batterie'>25.70</div><br />
<div class='infos_batterie_charge_current'>1.00</div><br /> <div class='infos_batterie_capacity'>95.00</div><br />
<div class='infos_PV_current'>1.00</div><br />
<div class='infos_PV_voltage'>78.00</div><br />
<div class='infos_batterie_discharge_current'>0.00</div><br /> <div class='infos_Grid_Voltage'>227.60</div><br />
<div class='infos_Grid_frequence'>49.90</div><br />
<div class='infos_output_Voltage'>230.10</div><br />
<div class='infos_BUS_voltage'>362</div><br />
<div class='infos_Inverter_heat_sink_temperature'>40.00</div><br /> <div class='infos_Battery_voltage_from_SCC'>25.64</div><br /> <div class='infos_PIP_status'>10111</div><br />
<div class='infos_dht_H_temp'>30.90</div><br />
<div class='infos_dht_H_humidity'>44.50</div><br />
<div class='infos_dht_B_temp'>24.60</div><br /> <div class='infos_dht_B_humidity'>62.30</div><br /> <div class='infos_RelayFanStatus'>1</div><br />
<div class='infos_date_stamp'>24/06/2022</div><br /> <div class='infos_time_stamp'>18:43</div><br />
<div class='infos_systeme'>WUI Version 6.8</div><br /> </body>
</html>

Les informations en face de chaque <div class de la page web produite par le module ARCELI peuvent être traduite dans Jeedom à l’aide du plugin « Script ».

Commencer par aller dans le Market pour installer le plugin suivant :

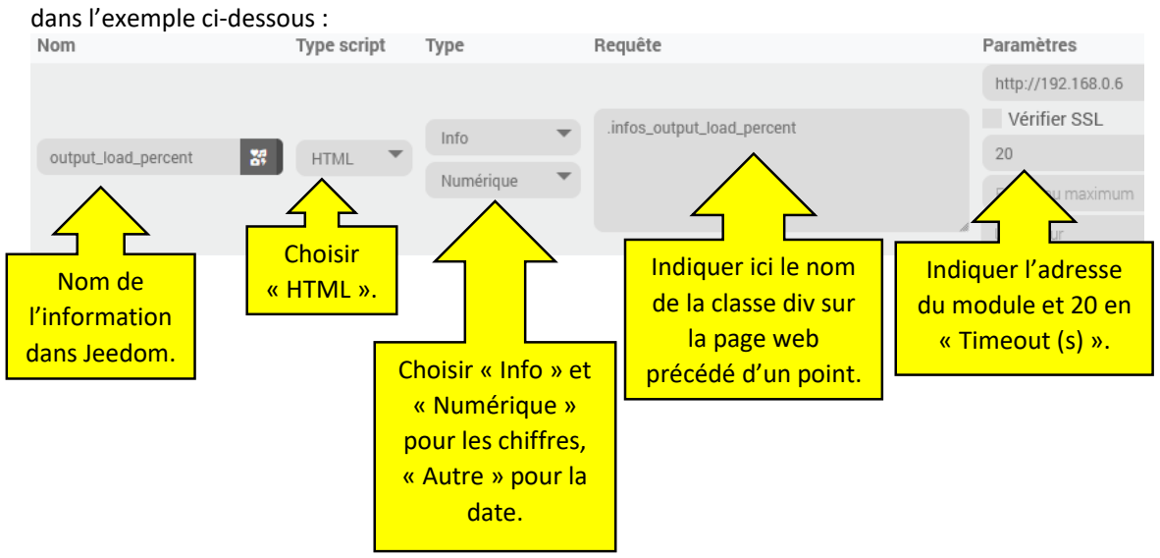
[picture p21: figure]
dans l’exemple ci-dessous :; Nom de l’information dans Jeedom.; Choisir « HTML ».; Choisir « Info » et « Numérique » pour les chiffres, « Autre » pour la date.; Indiquer ici le nom de la classe div sur la page web précédé d’un point.; Indiquer l’adresse du module et 20 en « Timeout (s) ».

Ajouter un nouveau script, nommer le « WKS » par exemple, puis configurer les commandes comme

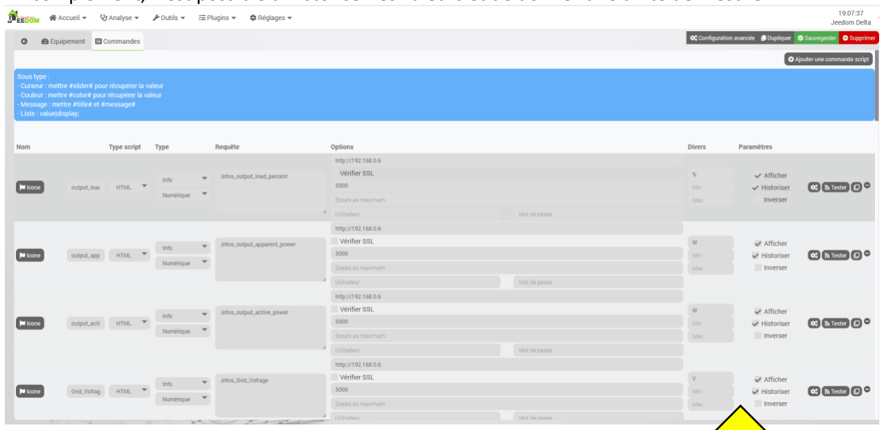
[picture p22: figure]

En complément, il est possible d’historiser les valeurs et de donner une unité de mesure :

Dans la version 7.2, j’ai ajouté la possibilité de redémarrer le module à l’aide d’un bouton « Reboot ». Pour cela il suffit d’ajouter une commande Action en indiquant l’adresse du module en http suivit de /Command?Rebboot, ce qui donne : http://192.168.0.6/Command?Reboot.

Information Importante : Si le script est exécuté toutes les 1 minute, le « Timeout (s) » des commandes d’information du script doit être positionné à 20. De même, le « Timeout (s) » des commandes d’action du script doit être positionné à 40.

Donner une unité de
mesure et cocher
« Historiser » si nécessaire.

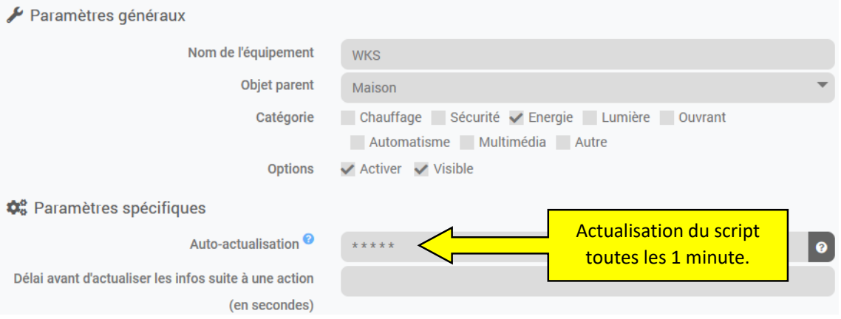
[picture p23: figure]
Actualisation du script toutes les 1 minute.

Finalement, avec une présentation de type « tableau » il est possible d’afficher sur son Dashboard Jeedom la présentation suivante (sur ma dernière version du logiciel 7.6) :

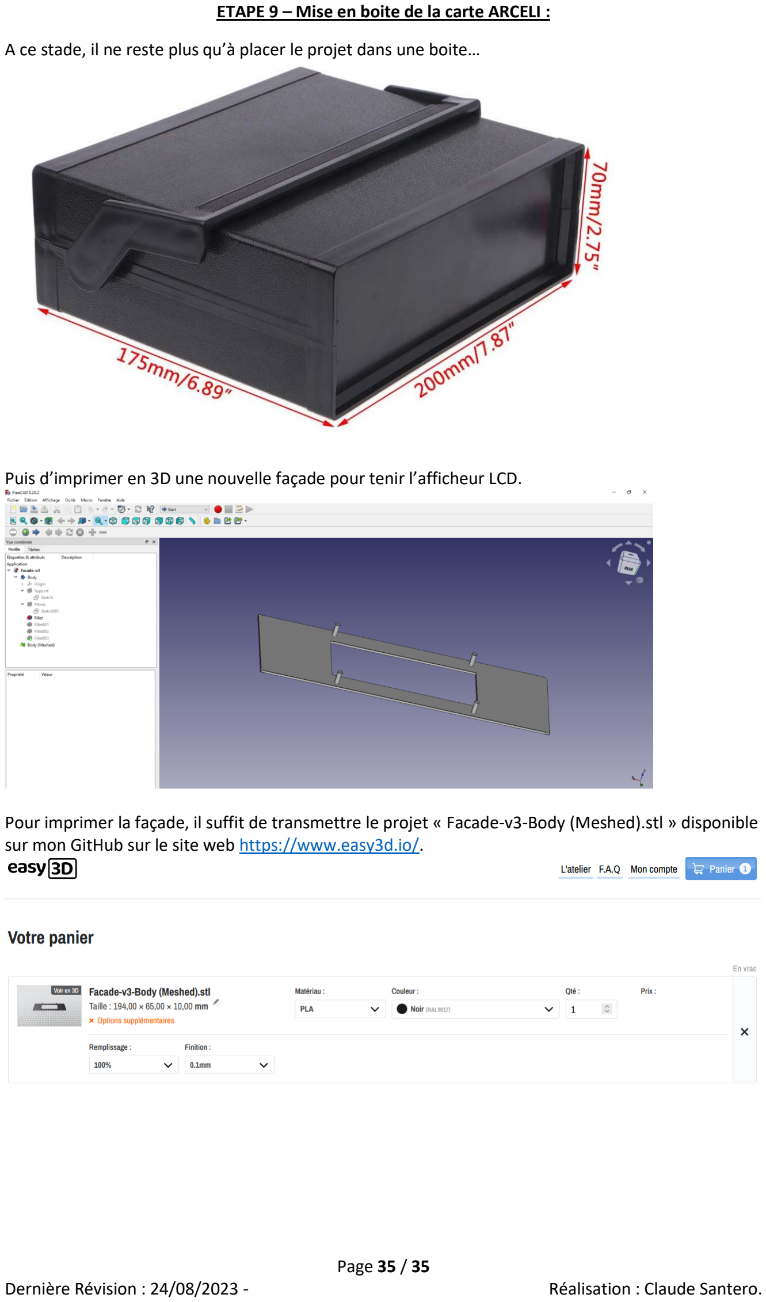
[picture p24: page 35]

ETAPE 9 – Mise en boite de la carte ARCELI :

A ce stade, il ne reste plus qu’à placer le projet dans une boite…

Puis d’imprimer en 3D une nouvelle façade pour tenir l’afficheur LCD.

Pour imprimer la façade, il suffit de transmettre le projet « Facade-v3-Body (Meshed).stl » disponible sur mon GitHub sur le site web https://www.easy3d.io/.

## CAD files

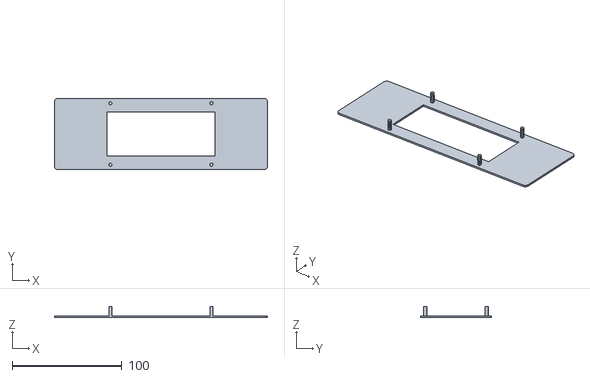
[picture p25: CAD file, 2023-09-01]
Facade-3D/Facade-v3-Body (Meshed).stl
194.0 x 65.0 x 10.0

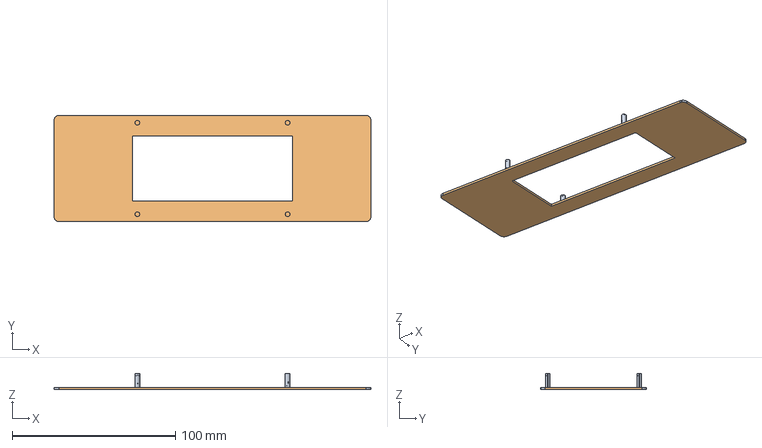
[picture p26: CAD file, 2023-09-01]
Facade-3D/Facade-v3.FCStd
194.0 x 65.0 x 10.0 mm
Body (Meshed)

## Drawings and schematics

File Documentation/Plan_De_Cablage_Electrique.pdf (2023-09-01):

J COFFRET DC | I ONDULEUR
- | + | - | +

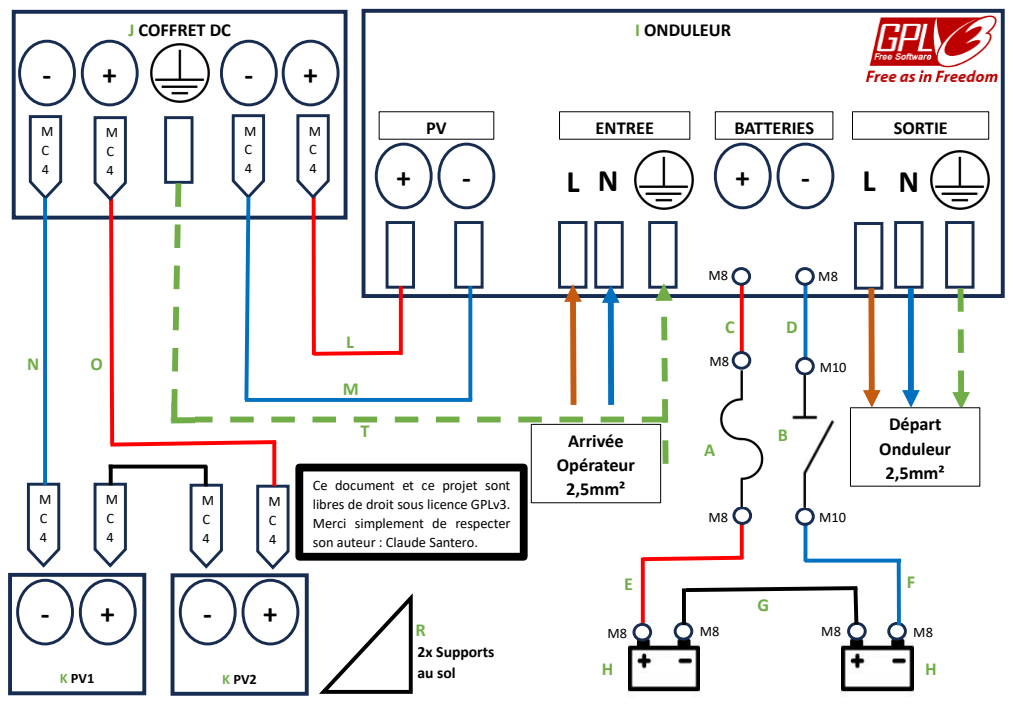
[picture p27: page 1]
2x Supports au sol; ENTREE; BATTERIES; SORTIE; Départ Onduleur 2,5mm²; Arrivée Opérateur 2,5mm²

Ce document et ce projet sont
libres de droit sous licence GPLv3.
Merci simplement de respecter
son auteur : Claude Santero.

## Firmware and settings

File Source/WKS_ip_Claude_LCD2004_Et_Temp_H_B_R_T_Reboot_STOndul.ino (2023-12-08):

#include <ESP8266WiFi.h>
#include <WiFiClient.h>

#include <TimeLib.h>
#include <time.h>        // https://github.com/PaulStoffregen/Time
#include <Timezone.h>    // https://github.com/JChristensen/Timezone
#include <WiFiUdp.h>
#include <NTPClient.h>

#include <ESP8266WebServer.h>
#include <ESP8266mDNS.h>
#include <SoftwareSerial.h>

#include <DHT.h>

#include<LiquidCrystal_I2C.h>

  // Paramètres WIFI...
  static const String monSSID = "MON-SSID";
  static const String monPass = "MON-PASSWORD-WIFI";
  static const String HostName = "WeMos_UPS";

  static const String WeMos_UPS_Version = "7.8";

  //Paramètres NTP...
  //  String months[12]={"Janvier", "Février", "Mars", "Avril", "Mai", "Juin", "Juillet", "Août", "Septembre", "Octobre", "Novembre", "Decembre"};
  String DateFR, TimeFR;
  int NTPUpdateResult; // Résultat Requète NTP : 0 Tant Qu'une requète NTP n'a pas aboutit, 1 Lorsqu'on a obtenu une requète NTP. 
  int NTPLastHourUpdate; // Heure de la dernière MAJ réussi de la requète NTP (MAJ demandé toutes les heures).
  int NTPLastDayUpdate; // Jour du dernier envoie de la dernière MAJ de la date et de l'heure de l'onduleur.
  int GTMOffset = 0; // SET TO UTC TIME + 1 Hour.
  WiFiUDP ntpUDP;
  NTPClient timeClient(ntpUDP, "europe.pool.ntp.org", GTMOffset*60*60, 60*60*1000); // NTPClient timeClient(ntpUDP, "pool.ntp.org", utcOffsetInSeconds);
  // Obtention du NTP depuis une source locale en 192.168.0.10 :
  //NTPClient timeClient(ntpUDP, "192.168.0.10", GTMOffset*60*60, 60*60*1000); // NTPClient timeClient(ntpUDP, "pool.ntp.org", utcOffsetInSeconds);
  // Central European Time (Frankfurt, Paris)
  TimeChangeRule CEST = {"CEST", Last, Sun, Mar, 2, 120};     // Central European Summer Time
  TimeChangeRule CET = {"CET ", Last, Sun, Oct, 3, 60};       // Central European Standard Time
  Timezone CE(CEST, CET);
  
  static tm getDateTimeByParams(long time){
    struct tm *newtime;
    const time_t tim = time;
    newtime = localtime(&tim);
    return *newtime;
  }
  
  // Paramètres LCD...
  LiquidCrystal_I2C lcd(0x27,20,4);
  static int QPOS;
   
  // Définition pour afficher un symbole degré sur le LCD...
  byte degre[8] = { // déclaration d’un tableau de 8 octets
        B00111, // définition de chaque octet au format binaire
        B00101, // 1 pour pixel affiché – 0 pour pixel éteint
        B00111, // les 3 bits de poids forts ne sont pas écrits car inutiles
        B00000,
        B00000,
        B00000,
        B00000,
      };
  static int caractereDegre;

  // Paramètre Du Relais Ventilos...
  static const float TempStartWKS = 32.50;  // Température de déclenchement des ventilos pour le WKS. 31.00
  static const float TempStopWKS = 29.50;   // Température d'arrêt des ventilos pour le WKS si ventilos démarrés. 27.00
  static const float TempStartBat = 25.50;  // Température de déclenchement des ventilos pour les batteries.
  static const float TempStopBat = 22.50;   // Température d'arrêt des ventilos pour les batteries si ventilos démarrés.
  static const int HStart = 2;              // Heure de lancement des ventilos forcée.
  static const int HStop = 7;               // Heure d'arrêt des ventilos forcée (heure comprise donc 7 signifie arrêt à 8H).
  static const int RelayFan = D7;           // Digital pin connected to Relay
  static int RelayFanStatus;

  // Paramètres De La Sonde De Température DHT...
  #define DHTPIN_H D4     // Digital pin connected to the DHT sensor (DHT Onduleur)
  #define DHTPIN_B D3     // Digital pin connected to the DHT sensor (DHT Batteries)

  // Uncomment the type of sensor in use:
  //#define DHTTYPE    DHT11     // DHT 11
  #define DHTTYPE    DHT22     // DHT 22 (AM2302)
  //#define DHTTYPE    DHT21     // DHT 21 (AM2301)

  DHT dht_H(DHTPIN_H, DHTTYPE);
  DHT dht_B(DHTPIN_B, DHTTYPE);

  // Utiliser isnan() permet de vérifier si la valeur n'est pas un nombre.
  float newT_H;   // Température Lu / isnan(newT) pour vérifier la valeur.
  float newH_H;   // Humidité Lu / isnan(newH) pour vérifier la valeur.

  float newT_B;   // Température Lu / isnan(newT) pour vérifier la valeur.
  float newH_B;   // Humidité Lu / isnan(newH) pour vérifier la valeur.

//* Time Function *

static String getDateTimeStringByParams(tm *newtime, char* pattern = (char *)"%d/%m/%Y %H:%M:%S"){
    char buffer[30];
    strftime(buffer, 30, pattern, newtime);
    return buffer;
}

static String getEpochStringByParams(long time, char* pattern = (char *)"%d/%m/%Y %H:%M:%S"){
//    struct tm *newtime;
    tm newtime;
    newtime = getDateTimeByParams(time);
    return getDateTimeStringByParams(&newtime, pattern);
}

void UpdateRTCWithNTP() {
  if (timeClient.update()){
     unsigned long epoch = timeClient.getEpochTime();
     setTime(epoch);
     NTPUpdateResult = 1; // 1 Requète NTP a aboutit.
     NTPLastHourUpdate = getEpochStringByParams(CE.toLocal(now()),(char*)"%H").toInt();
     Serial.println("Horloge RTC Mise A Jour Avec Temps NTP @ " + String(NTPLastHourUpdate) + " H.");
  } else{
         Serial.println("Echec De La Requète NTP." );
        }
}

void ReadNTPTime() {
  DateFR = getEpochStringByParams(CE.toLocal(now()),(char*)"%d/%m/%Y"); //"%d/%m/%Y %H:%M:%S"
  TimeFR = getEpochStringByParams(CE.toLocal(now()),(char*)"%H:%M"); //"%d/%m/%Y %H:%M:%S"
}

//* End Of Time Function *

// * Temp Function *

  void FanCTRL()
  {
    String HR = getEpochStringByParams(CE.toLocal(now()),(char*)"%H"); //"%d/%m/%Y %H:%M:%S"
    int HH = HR.toInt();
    
    if (HH >= HStart && HH <= HStop)
    {
      pinMode(RelayFan , INPUT); // Démarre ventilation sur NC.
      RelayFanStatus = 2;
      Serial.println("Ventilos Démarrés en mode horraire.");
    }
    else
    { // ***********************************************************************************************
     if (newT_B < 0 || newT_H < 0)
     {
      // Absence de données des sondes on met les ventilos en service... 
      pinMode(RelayFan , INPUT); // Démarre ventilation sur NC.
      RelayFanStatus = 1;
      Serial.println("Ventilos Démarrés.");
     }
     else
     {
      if (newT_B >= TempStartBat || newT_H >= TempStartWKS) 
      {
       // Température suppérieure ou égale à au moins un TempStart : On démarre les ventilos...
       pinMode(RelayFan , INPUT); // Démarre ventilation sur NC.
       RelayFanStatus = 1;
       Serial.println("Ventilos Démarrés.");
      }
      else 
      { 
       // Température strictement inférieure aux TempStart on arrête les ventilos si les températures sont inférieures ou égales aux seuils TempStopForBat ET TempStopWKS...
       if (newT_B <= TempStopBat && newT_H <= TempStopWKS)
       {
        pinMode(RelayFan , OUTPUT); // Arrêt ventilation sur NC.
        RelayFanStatus = 0;
        Serial.println("Ventilos Arrêtés.");
       }
      }
     }
    } // ***********************************************************************************************
  }
  
  void ReadTempHum()
  {
    newT_H = dht_H.readTemperature();
    newT_B = dht_B.readTemperature();
    
    // Read temperature as Fahrenheit (isFahrenheit = true)
    //float newT = dht.readTemperature(true);
    // if temperature read failed, don't change t value
    //lcd.setCursor(0,2);
    if (isnan(newT_H)) // isnan() permet de vérifier si la valeur n'est pas un nombre.
    { 
      newT_H = -1;
      Serial.println("Failed to read from DHT_H sensor!");
    }
    else 
    {
     Serial.print("Reading Temp. H : ");
     Serial.println(newT_H);
    }

    if (isnan(newT_B)) // isnan() permet de vérifier si la valeur n'est pas un nombre.
    { 
      newT_B = -1;
      Serial.println("Failed to read from DHT_B sensor!");
    }
    else 
    {
     Serial.print("Reading Temp. B : ");
     Serial.println(newT_B);
    }
    
    // Read Humidity
    newH_H = dht_H.readHumidity();
    newH_B = dht_B.readHumidity();
    // if humidity read failed, don't change h value 
    if (isnan(newH_H)) 
    { 
      newH_H = -1;
      Serial.println("Failed to read from DHT_H sensor!");
    }
    else 
    {
     Serial.print("Reading Humidity H : ");
     Serial.println(newH_H);
    }

    if (isnan(newH_B)) 
    { 
      newH_B = -1;
      Serial.println("Failed to read from DHT_B sensor!");
    }
    else 
    {
     Serial.print("Reading Humidity B : ");
     Serial.println(newH_H);
    }

    FanCTRL();
        
    lcd.setCursor(0,2);
    if (newT_H < 0 || newH_H < 0) lcd.print("TH : DHT Failed.   *");
     else {
           lcd.print("TH : " + String(newT_H));
           lcd.write(caractereDegre); // affiche le caractère
           lcd.print("C/"+String(newH_H)+"%");
           if (RelayFanStatus == 1 && newT_H >= TempStartWKS) lcd.print("*");
            else lcd.print("."); 
          }
    lcd.setCursor(0,3);
    if (newT_B < 0 || newH_B < 0) lcd.print("TB : DHT Failed.   *");
     else {
           lcd.print("TB : " + String(newT_B));
           lcd.write(caractereDegre); // affiche le caractère
           lcd.print("C/"+String(newH_B)+"%");
           if (RelayFanStatus == 1 && newT_B >= TempStartBat) lcd.print("*");
            else lcd.print("."); 
          }
  }

// * End Of Temp Function *

//* CRC-CCITT Function *

    // CRC16-CITT - Xmodem implement
    uint16_t calc_crc(const char *msg,int n)
    {
      // Initial value. xmodem uses 0xFFFF but this example
      // requires an initial value of zero.
      uint16_t x = 0;
      
      while(n--) {
        x = crc_xmodem_update(x, (uint16_t)*msg++);
      }
      return(x);
    }
    
    // See bottom of this page: http://www.nongnu.org/avr-libc/user-manual/group__util__crc.html
    // Polynomial: x^16 + x^12 + x^5 + 1 (0x1021)
    uint16_t crc_xmodem_update (uint16_t crc, uint8_t data)
    {
      int i;
      
      crc = crc ^ ((uint16_t)data << 8);
      for (i=0; i<8; i++) {
        if (crc & 0x8000)
          crc = (crc << 1) ^ 0x1021; //(polynomial = 0x1021)
        else
          crc <<= 1;
      }
      return crc;
    }
    
// * End Of CRC-CCITT Function *

    // Paramètres Onduleurs WKS & WebServer...
    String QPIGS = "\x51\x50\x49\x47\x53\xB7\xA9\x0D"; //Lecture live data (QPIGS + CRC + CR)
    String QPIWS = "\x51\x50\x49\x57\x53\xB4\xDA\x0D";  
    String QDI = "\x51\x44\x49\x71\x1B\x0D";
    String QMOD = "\x51\x4D\x4F\x44\x49\xC1\x0D"; 
    String QVFW =  "\x51\x56\x46\x57\x62\x99\x0D"; 
    String QVFW2 = "\x51\x56\x46\x57\x32\xC3\xF5\x0D"; 
    
    float PIP_Grid_Voltage=0;
    float PIP_Grid_frequence=0;
    float PIP_output_Voltage=0;
    float PIP_output_frequence=0;
    int PIP_output_apparent_power=0;
    int PIP_output_active_power=0;
    int PIP_output_load_percent=0;
    int PIP_BUS_voltage=0;
    float PIP_Battery_voltage=0;
    float PIP_battery_charge_current=0;
    float PIP_battery_capacity=0;
    float PIP_Inverter_heat_sink_temperature=0;
    float PIP_PV_current=0;
    float PIP_PV_voltage=0;
    float PIP_Battery_voltage_from_SCC =0;
    float PIP_battery_discharge_current=0;
    int PIP_status;
    String Resultat="";

    String LastInverterCMD_Date_Time;
    String LastInverterCMD_Response;
    
    ESP8266WebServer server(80);
    // MDNSResponder mdns; // Retiré par Claude.
    SoftwareSerial Serial2(D6,D5); //GPOI12(D6)->Rx & GPOI14(D5)->Tx

    /*
     Sending Date Time to Inverter :
     
     3.29 DAT<YYMMDDHHMMSS><cr>: Date and time
     Computer: DAT<YYMMDDHHMMSS><cr>
     <Y, M, D, H, S> is an integer number 0 to 9.
     Device: (ACK<cr> if Device accepts this command, otherwise, responds (NAK<cr>
    */
    void SetInverterDateTime()
    {
     static String CMD;
     static uint16_t crc_out;
     static char lo;
     static char hi;

     Serial.println("Calling SetInverterDateTime...");
     const int CurrentDay = getEpochStringByParams(CE.toLocal(now()),(char*)"%d").toInt(); 
     if (NTPLastDayUpdate == 0 && NTPUpdateResult)
     {
      // Démarrage du module on met l'onduleur à l'heure...
      Serial.println("1er lancement.");
      CMD = getEpochStringByParams(CE.toLocal(now()),(char*)"%Y%m%d%H%M%S");
      CMD = "DAT" + CMD.substring(2);
      LastInverterCMD_Date_Time = CMD;
      const char *ccmd = CMD.c_str();
      crc_out = calc_crc(ccmd,CMD.length());
      lo = crc_out & 0xFF;
      hi = crc_out >> 8;
      CMD = CMD + lo + hi + "\x0D"; // CMD = CMD + lo + hi + "\x0D";
      Serial.println("CMD :: "+CMD);
      Serial2.print(CMD);
      Serial2.flush(); 
      if (Serial2.find("ACK"))
      {
       Serial.println("ACK");
       LastInverterCMD_Response = "ACK"; 
      }
      else
      {
       Serial.println("NAK");
       LastInverterCMD_Response = "NAK"; 
      } 
      Serial.println("Inverter Answer : " + LastInverterCMD_Response + ".");
      NTPLastDayUpdate = CurrentDay; 
     }
     else
     {
      // Mise à l'heure 1 fois par jour à 6H du matin...
      Serial.println("Mise à l'heure horodaté tous les jours à 6H...");
      Serial.println("CurrentDay = " + String(CurrentDay) +".");
      Serial.println("NTPLastDayUpdate = " + String(NTPLastDayUpdate)+".");
      if (NTPLastDayUpdate != CurrentDay && NTPUpdateResult)
      {
       // Mise à jour de l'onduleur tous les jours à 6 heure du matin...
       const int CurrentHour = getEpochStringByParams(CE.toLocal(now()),(char*)"%H").toInt();
       Serial.println("CurrentHour = " + String(CurrentHour)+".");
       if (CurrentHour == 6 && NTPUpdateResult)
       {
        CMD = getEpochStringByParams(CE.toLocal(now()),(char*)"%Y%m%d%H%M%S");
        CMD = "DAT" + CMD.substring(2);
        LastInverterCMD_Date_Time = CMD;
        const char *ccmd = CMD.c_str();
        crc_out = calc_crc(ccmd,CMD.length());
        lo = crc_out & 0xFF;
        hi = crc_out >> 8;  
        CMD = CMD + lo + hi + "\x0D"; // CMD = CMD + lo + hi + "\x0D";
        Serial.println("CMD :: "+CMD);
        Serial2.print(CMD);
        Serial2.flush(); 
        if (Serial2.find("ACK"))
        {
         Serial.println("ACK");
         LastInverterCMD_Response = "ACK"; 
        }
        else
        {
         Serial.println("NAK");
         LastInverterCMD_Response = "NAK"; 
        } 
        Serial.println("Inverter Answer : " + LastInverterCMD_Response + ".");
        NTPLastDayUpdate = CurrentDay;
       }
      }
     }
    }
    
    void read_PIP() {
        Serial2.print(QPIGS);
        Serial2.flush(); 
           
        if (Serial2.find("(")) {
            PIP_Grid_Voltage=Serial2.parseFloat();
            PIP_Grid_frequence=Serial2.parseFloat();
            PIP_output_Voltage=Serial2.parseFloat();
            PIP_output_frequence=Serial2.parseFloat();
            PIP_output_apparent_power=Serial2.parseInt();
            PIP_output_active_power=Serial2.parseInt();
            PIP_output_load_percent=Serial2.parseInt();
            PIP_BUS_voltage=Serial2.parseFloat();
            PIP_Battery_voltage=Serial2.parseFloat();
            PIP_battery_charge_current=Serial2.parseFloat();
            PIP_battery_capacity=Serial2.parseInt();
            PIP_Inverter_heat_sink_temperature =Serial2.parseInt();
            PIP_PV_current=Serial2.parseFloat();
            PIP_PV_voltage=Serial2.parseFloat();
            PIP_Battery_voltage_from_SCC =Serial2.parseFloat();
            PIP_battery_discharge_current=Serial2.parseFloat();
            PIP_status=Serial2.parseInt();
    
            Serial.println(PIP_Grid_Voltage);
            Serial.println(PIP_Grid_frequence);
            Serial.println(PIP_output_Voltage);
            Serial.println(PIP_output_frequence);
            Serial.println(PIP_output_apparent_power);
            Serial.println(PIP_output_active_power);
            Serial.println(PIP_output_load_percent);
            Serial.println(PIP_BUS_voltage);
            Serial.println(PIP_Battery_voltage);
            Serial.println(PIP_battery_charge_current);
            Serial.println(PIP_battery_capacity);
            Serial.println(PIP_Inverter_heat_sink_temperature);
            Serial.println(PIP_PV_current);
            Serial.println(PIP_PV_voltage);
            Serial.println(PIP_Battery_voltage_from_SCC);
            Serial.println(PIP_battery_discharge_current);
            Serial.println(PIP_status);
      }
    }

    void handleRoot(){
      int CurrentTime = getEpochStringByParams(CE.toLocal(now()),(char*)"%H").toInt();
      if (CurrentTime != NTPLastHourUpdate) UpdateRTCWithNTP();
      ReadNTPTime();
      
      if (!NTPUpdateResult)
      {
        DateFR = "*";
        TimeFR = "*";
        lcd.setCursor(0,0);
        lcd.print("NTP Failed.         ");
      }
      
      Serial.print("Lecture Du Port COM De L'onduleur à ");
      Serial.println(DateFR+" - "+TimeFR+".");
      
      read_PIP();
      delay(5000);
      Serial.println("Creation De La Page Web De Resultat.");

      // Lecture Des Informations DHT (Température & Humidité)...
      ReadTempHum();
      String TemperatureH;
      if (newT_H < 0) TemperatureH = "-1";
       else TemperatureH = String(newT_H);
      String TemperatureB;
      if (newT_B < 0) TemperatureB = "-1";
       else TemperatureB = String(newT_B);
      
      String HumidityH;
      if (newH_H < 0) HumidityH = "-1";
       else HumidityH = String(newH_H);
      String HumidityB;
      if (newH_B < 0) HumidityB = "-1";
       else HumidityB = String(newH_B);
       
      String INDEX_HTML = "";
      INDEX_HTML +="<!DOCTYPE HTML>";
      INDEX_HTML +="<html>";
      INDEX_HTML +="<head></head>";
      INDEX_HTML +="<body style='text-align:center;'>";
      INDEX_HTML +="<div class='infos_output_frequence'>"; INDEX_HTML += String(PIP_output_frequence); INDEX_HTML +="</div><br />"; // Frequence sortante
      INDEX_HTML +="<div class='infos_output_apparent_power'>"; INDEX_HTML += String(PIP_output_apparent_power); INDEX_HTML +="</div><br />"; // Puissance Apparente sortante
      INDEX_HTML +="<div class='infos_output_active_power'>"; INDEX_HTML += String(PIP_output_active_power); INDEX_HTML +="</div><br />"; // Puissance Active sortante
      INDEX_HTML +="<div class='infos_output_load_percent'>"; INDEX_HTML += String(PIP_output_load_percent); INDEX_HTML +="</div><br />"; // Charge sortante (%)
      INDEX_HTML +="<div class='infos_batterie'>"; INDEX_HTML += String(PIP_Battery_voltage); INDEX_HTML += "</div><br />"; // Tension de batterie
      INDEX_HTML +="<div class='infos_batterie_charge_current'>"; INDEX_HTML += String(PIP_battery_charge_current); INDEX_HTML += "</div><br />"; // Courant de chargement de Batterie
      INDEX_HTML +="<div class='infos_batterie_capacity'>"; INDEX_HTML += String(PIP_battery_capacity); INDEX_HTML +="</div><br />"; // Capacite de batterie
      INDEX_HTML +="<div class='infos_PV_current'>"; INDEX_HTML += String(PIP_PV_current); INDEX_HTML += "</div><br />"; // Courant photovoltaique
      INDEX_HTML +="<div class='infos_PV_voltage'>"; INDEX_HTML += String(PIP_PV_voltage); INDEX_HTML += "</div><br />"; // Tension photovoltaique entrante
      INDEX_HTML +="<div class='infos_PV_power'>"; INDEX_HTML += String(PIP_PV_voltage * PIP_PV_current); INDEX_HTML += "</div><br />"; // Tension photovoltaique entrante
      INDEX_HTML +="<div class='infos_batterie_discharge_current'>"; INDEX_HTML += String(PIP_battery_discharge_current); INDEX_HTML += "</div><br />"; // Courant de decharge de batterie
      
      INDEX_HTML +="<div class='infos_Grid_Voltage'>"; INDEX_HTML += String(PIP_Grid_Voltage); INDEX_HTML += "</div><br />";
      INDEX_HTML +="<div class='infos_Grid_frequence'>"; INDEX_HTML += String(PIP_Grid_frequence); INDEX_HTML += "</div><br />";
      INDEX_HTML +="<div class='infos_output_Voltage'>"; INDEX_HTML += String(PIP_output_Voltage); INDEX_HTML += "</div><br />";
//      INDEX_HTML +="<div class='infos_BUS_voltage'>"; INDEX_HTML += String(PIP_BUS_voltage); INDEX_HTML += "</div><br />";
      INDEX_HTML +="<div class='infos_Inverter_heat_sink_temperature'>"; INDEX_HTML += String(PIP_Inverter_heat_sink_temperature); INDEX_HTML += "</div><br />";
      INDEX_HTML +="<div class='infos_Battery_voltage_from_SCC'>"; INDEX_HTML += String(PIP_Battery_voltage_from_SCC); INDEX_HTML += "</div><br />";
      INDEX_HTML +="<div class='infos_PIP_status'>"; INDEX_HTML += String(PIP_status); INDEX_HTML += "</div><br />";
      
      INDEX_HTML +="<div class='infos_dht_H_temp'>"; INDEX_HTML += String(TemperatureH); INDEX_HTML += "</div><br />"; // Courant de decharge de batterie
      INDEX_HTML +="<div class='infos_dht_H_humidity'>"; INDEX_HTML += String(HumidityH); INDEX_HTML += "</div><br />"; // Courant de decharge de batterie
      INDEX_HTML +="<div class='infos_dht_B_temp'>"; INDEX_HTML += String(TemperatureB); INDEX_HTML += "</div><br />"; // Courant de decharge de batterie
      INDEX_HTML +="<div class='infos_dht_B_humidity'>"; INDEX_HTML += String(HumidityB); INDEX_HTML += "</div><br />"; // Courant de decharge de batterie
      INDEX_HTML +="<div class='infos_RelayFanStatus'>"; INDEX_HTML += String(RelayFanStatus); INDEX_HTML += "</div><br />"; // Courant de decharge de batterie
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
void loop() {
  server.handleClient();

  // Une Requète NTP toutes les heures...
  int CurrentTime = getEpochStringByParams(CE.toLocal(now()),(char*)"%H").toInt();
  if (CurrentTime != NTPLastHourUpdate) UpdateRTCWithNTP();
  ReadNTPTime();
  lcd.setCursor(0,0);
  if (NTPUpdateResult) 
  { 
   SetInverterDateTime();
   if (RelayFanStatus == 1) lcd.print("*");
    else if (RelayFanStatus == 2) lcd.print("+");
          else lcd.print(" ");
    lcd.print(DateFR + " - " + TimeFR);
  }
   else
  {  
   lcd.print("NTP Failed.    "); 
   UpdateRTCWithNTP();
  }
  if (RelayFanStatus == 1) lcd.print("*");
   else if (RelayFanStatus == 2) lcd.print("+");
         else lcd.print(" ");
  ReadTempHum(); 
//  Serial.print("Current date: ");
//  Serial.println(DateFR);
//  Serial.println(timeClient.getFormattedTime());
//  delay(100);
}

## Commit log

2023-09-01 Release Initiale - Septembre 2023
    [Facade-v3-Body (Meshed).stl, Facade-v3.FCStd]
2023-12-08 Correction mise à l'heure de l'onduleur
    [WKS_ip_Claude_LCD2004_Et_Temp_H_B_R_T_Reboot_STOndul.ino]
2023-12-12 Ajout de Plan_De_Cablage_Electrique_Element_Positon_Plan au format PDF
